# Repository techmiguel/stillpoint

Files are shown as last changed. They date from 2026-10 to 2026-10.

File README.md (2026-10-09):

<p align="center">
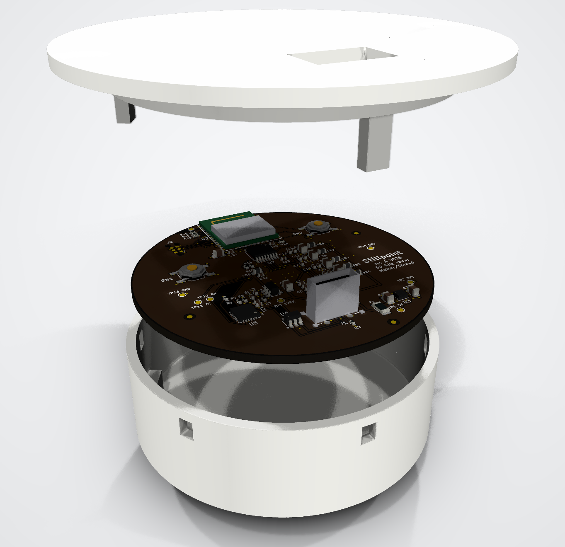
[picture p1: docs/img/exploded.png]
Stillpoint exploded view: lid, board and enclosure with its radome
  
</p>

<h1 align="center">Stillpoint</h1>

<p align="center">
  <b>A privacy-first ceiling sensor that counts people, knows their posture and reports falls,<br>
  using a 60 GHz radar instead of a camera.</b>
</p>

<p align="center">
  
  
  
</p>

<p align="center"><a href="https://techmiguel.github.io/stillpoint/"><b>Project page →</b></a></p>

- **Sees the room, never the person.** No camera, no microphone. A 60 GHz FMCW radar
  (Infineon BGT60TR13C) measures where people are and how they move.
- **Finds people who are perfectly still**, by the movement of their chest as they
  breathe, so someone sitting or lying quietly does not "disappear".
- **Counts people, tracks position and posture, and reports falls**, all from one stream:
  no modes to switch between.
- **Runs entirely on the device** (Silicon Labs MGM260P / EFR32MG26) and reports over
  **Matter on Thread** with standard clusters: no cloud, no account, works with Home
  Assistant.
- **Open hardware**: KiCad schematic and 4-layer Ø60 mm board, FreeCAD enclosure, C
  firmware and the Python reference it is tested against.

> **Not a medical device.** A fall alert is a notification, never the only safety measure
> for a person.

## The board

| Top (ceiling side) | Bottom (radar, faces the floor) |
|---|---|
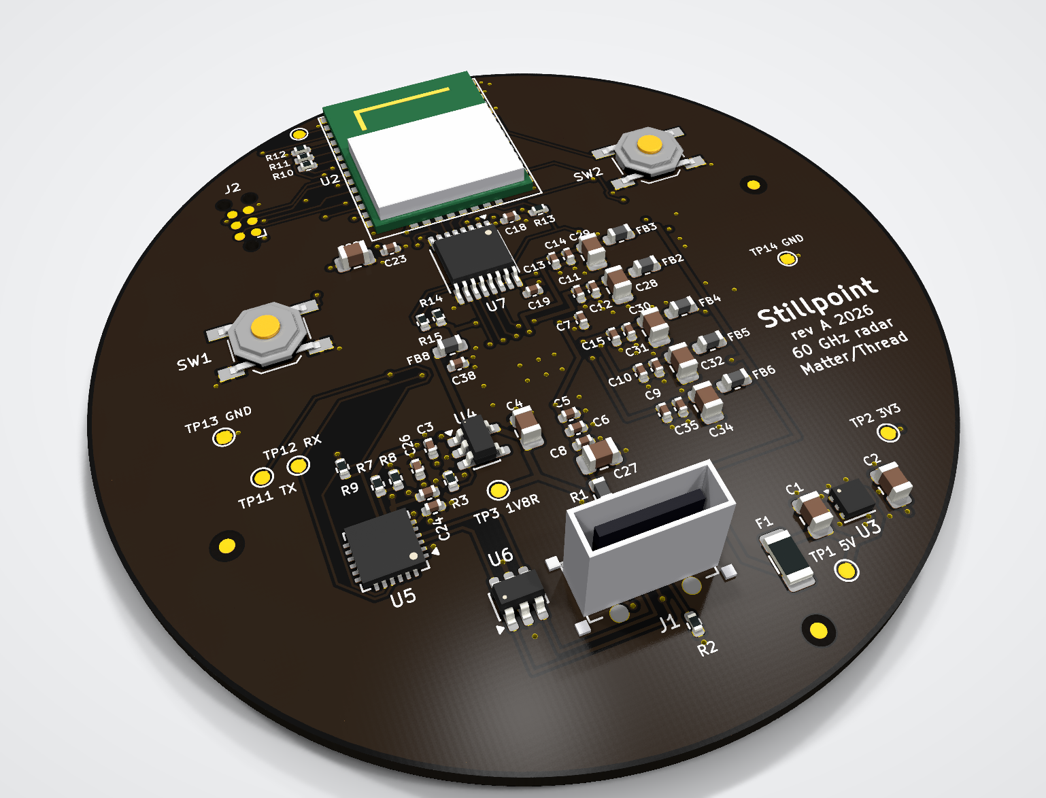
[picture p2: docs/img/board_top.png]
Stillpoint board, top
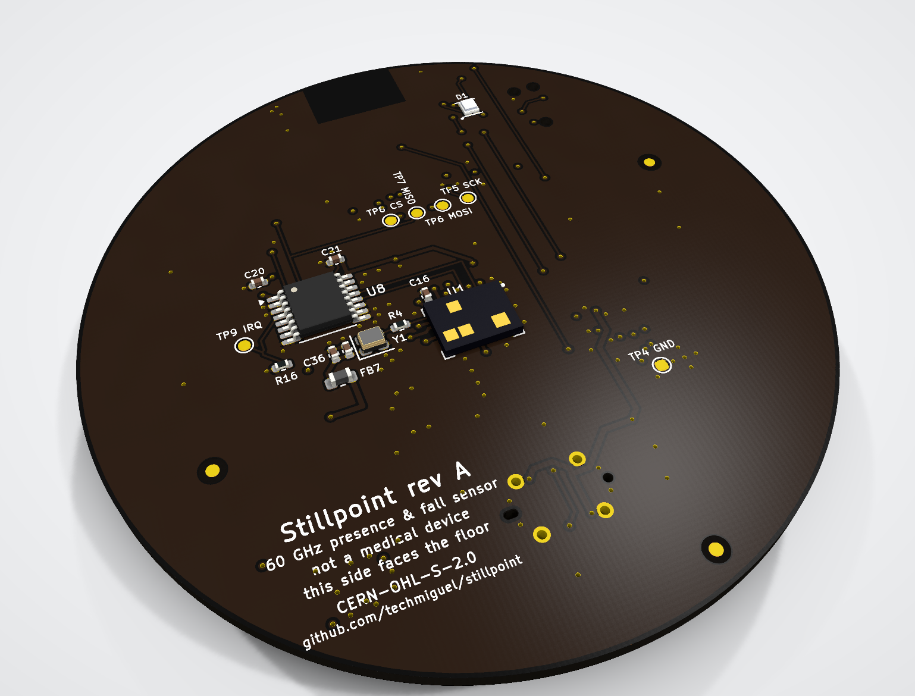
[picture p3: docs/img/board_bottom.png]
Stillpoint board, bottom
|  |  |

| | |
|---|---|
| Size | Ø60 mm round, 4 layers, 1.6 mm, ENIG, JLCPCB standard process |
| Radar | BGT60TR13C on the bottom face, 0.5 mm-pitch BGA, antennas in package |
| Radio + CPU | MGM260P module (Cortex-M33 + MVP accelerator, Matter/Thread/BLE) at the board edge with its antenna keep-out |
| Power | USB-C, 3.3 V LDO, 7 µVrms 1.8 V LDO for the radar, one π filter per radar supply domain |
| Extras | CP2102N USB console, RGB status LED, setup/reset buttons, Tag-Connect SWD, 14 test points |

Layout highlights:

- **Radar ground done by the book.** Solid ground on L2, a ground island on L3 right under
  the chip, nothing but ground vias inside the ball ring, and a custom DRC rule that keeps
  every other net off the inner layers under the radar.
- **Every radar supply is a straight lane** from its ball through 100 nF → 1 µF → 10 µF to
  its ferrite, with the smallest capacitor closest to the ball (Infineon's reference
  filter).
- **No crossing radar lines.** The radar signals leave the MCU from the pad row that faces
  the level translators, and the two translators are split over both faces to match the
  radar's ball order.

Fabrication files (Gerber, drill, BOM and CPL for JLCPCB, schematic PDF, STEP) are in
[`hardware/fabrication/`](hardware/fabrication) and attached to the
[rev A release](https://github.com/techmiguel/stillpoint/releases/tag/rev-a).
Full design notes: [docs/hardware.md](docs/hardware.md).

## The enclosure

A Ø65 mm, 24 mm tall ceiling puck on a Ø77 mm ceiling plate, 3D-printed in natural PETG.
The bottom of the shell is the radome: a flat slab exactly half a wavelength thick inside
the plastic (1.48 mm), so the 60 GHz signal passes through with about 0.15 dB of loss, and
the radar's antennas sit one wavelength (4.95 mm) above it. The board rests on three supports and the lid clamps it
with three posts at the same angles; the USB-C cable leaves through the lid, against the
ceiling.

The FreeCAD model ([`mechanical/enclosure.py`](mechanical/enclosure.py)) loads the real
board STEP and checks that nothing touches the shell, the lid or the radome, and that no
plastic sits in the antennas' ±60° field of view.

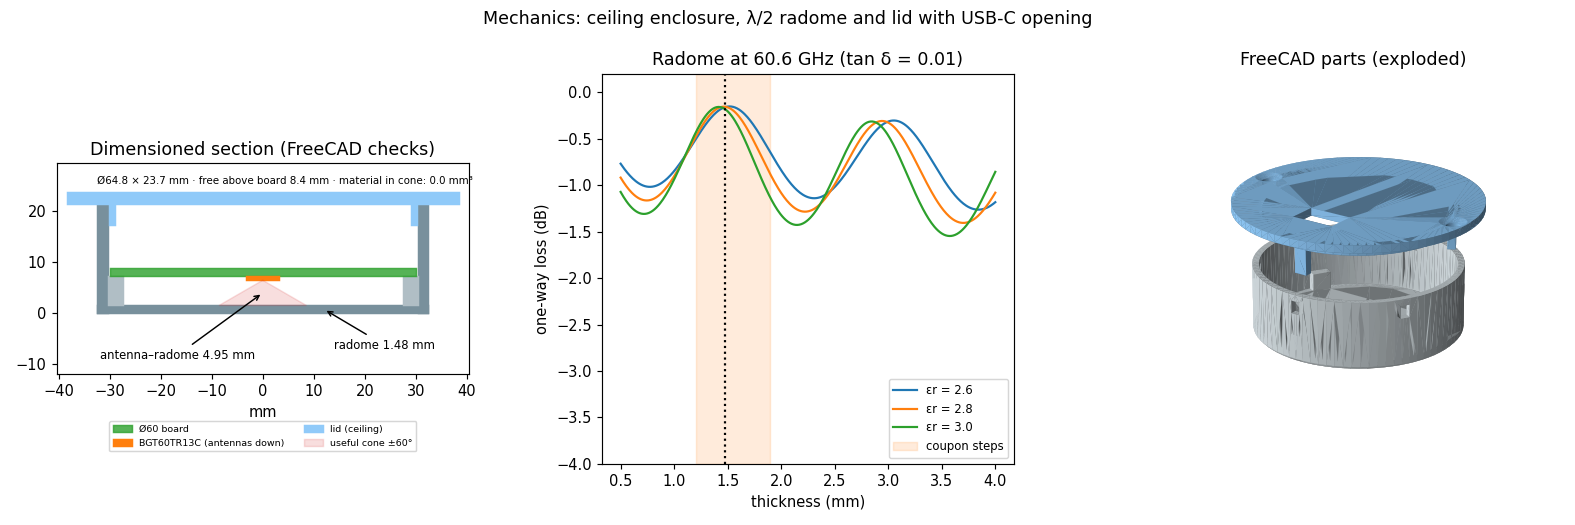
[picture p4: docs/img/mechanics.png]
Enclosure section, radome transmission and parts


## How it works

```
ADC (3 RX × 32 chirps × 128 samples, 10 Hz)
  → range FFT ─┬─ motion path: MTI + Doppler + CFAR + angle   (people who move)
               └─ micro-motion path: 10 s of phase, breathing  (people who are still)
  → 3D detections → tracks with room logic (doors, occlusion, ghosts)
  → 66-byte feature record per track (the contract)
  → int8 CNN (14.6 KB) every 0.5 s → fail-safe decision → Matter
```

The fixes for the classic failures of commercial radar sensors are regression tests:

| Scenario | What the sensor does |
|---|---|
| A person sits still and someone walks in front of them | the hidden person is kept as *occluded*, never dropped |
| An empty room with a fan running | the fan is learned as an interferer and not counted |
| Someone walks next to a mirror | the mirror ghost is recognised as multipath |
| A fall | suspected by the model or by a fast drop to the floor, confirmed after 4 s still on the floor; if it cannot be verified it is reported as *uncertain*, never silenced ([plot](docs/img/fall_events.png)) |

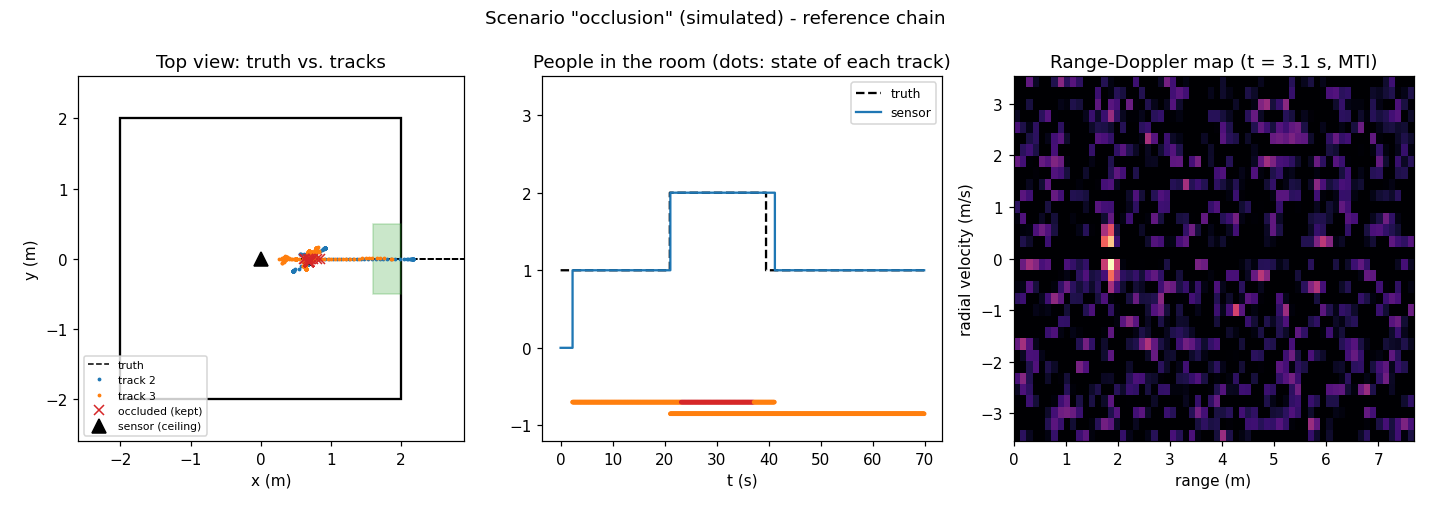
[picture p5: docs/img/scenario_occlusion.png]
occlusion scenario


The C firmware is checked frame by frame against the Python reference: same counts,
≥ 99.8 % identical quantized features, and identical postures, fall decisions and alarm
times ([plot](docs/img/app_c_vs_python.png)).

## License

[CERN-OHL-S-2.0](LICENSE) (CERN Open Hardware Licence v2, strongly reciprocal) for the
whole project: schematic, board, mechanics, firmware and documentation.

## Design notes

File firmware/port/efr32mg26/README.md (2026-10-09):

# EFR32MG26 port (Matter over Thread)

Everything that does not depend on the SDK lives in `firmware/src/` and is
tested on the PC against the Python reference
(`cd ml && python -m unittest discover -s tests`). This folder holds only the
layer that **does** depend on the Silicon Labs SDK. It has **not been built
against the real SDK yet**. `radar_port.c` and `diag_uart.c` pass
`gcc -fsyntax-only -Wall -Wextra` against stub headers that carry the SDK and
Infineon driver signatures. That rules out type and name errors, not mismatches
with the real signatures. Building and testing with the kit is phase F2.

| File | What it does | Status |
|---|---|---|
| `radar_port.c` | Infineon driver platform hooks (SPI, CS, RST, delay), FIFO interrupt, radar task | syntax-checked |
| `radar_settings_check.h` | refuses to build with a `radar_settings.h` that differs from config v1 | not built |
| `radar_pins.h` | rev A board pins (radar, LED, button, console) | matches `hardware/` and `verification/pcb/pins.yaml` |
| `matter_bridge.cpp` | `rf_outputs_t` → Matter attributes (EP1–6 plus the manufacturer cluster with `ContractVersion` and `ModelHash`), at most 2 reports/s except alarms | not built; ZAP generates the `StillpointPresence::…` accessors from the XML |
| `app_radar_init.cpp` | start-up from `AppTask::AppInit` | not built |
| `diag_uart.c` | contract records over UART with COBS (`tools/diag_reader.py`) and command input (room configuration from `tools/room_cfg.py`, acknowledged) | COBS tested on PC; syntax-checked |
| `cfg_store.c` | room configuration in NVM3 (v1 layout from `src/room_cfg.h`); factory default when none is valid | `room_cfg.c` tested on PC against the Python tool; syntax-checked |
| `stillpoint_cluster.xml` | manufacturer cluster for ZAP | not validated in ZAP |

## Steps (F2)

1. Simplicity Studio 5 + Simplicity SDK + Silicon Labs Matter extension.
2. New project from the **Matter – SoC Occupancy Sensor (Thread)** example for the
   EFR32MG26 board.
3. Components: `spidrv` (instance `radar`, EUSART1, 12 MHz to start with; on the
   rev A board SCLK PA07, MOSI PA08, MISO PC00 and CS as GPIO, see `radar_pins.h`),
   `gpiointerrupt`, `sleeptimer`, `iostream_eusart` or `iostream_usart` for
   diagnostics (3 Mbaud, non-blocking reads) and `nvm3_default`. Check that the
   NVM3 key in `cfg_store.c` (0x0F600) is outside the range Matter reserves.
   The board's module is the MGM260PB32VNA5 (+20 dBm, the same as the kit); the
   3.3 V regulator (TLV75733P, 1 A) is sized for its TX peaks (budget in
   [`docs/hardware.md`](../../../docs/hardware.md)).
4. Add `firmware/src/*.c` (except tests), this folder and Infineon's
   `sensor-xensiv-bgt60trxx` library (Apache-2.0) without its `*_mtb.c`.
5. Export `radar_settings.h` from **Infineon Radar Fusion GUI** with:

   | Parameter | Value |
   |---|---|
   | Start / stop frequency (sampled) | 60.0 / 61.25 GHz |
   | Samples per chirp | 128 at 2 MS/s |
   | Chirps per frame | 32, 350 µs repetition |
   | Frame | 100 ms (10 Hz) |
   | RX | 1, 2, 3 · TX 1 |

   `radar_settings_check.h` fails the build if anything differs.
6. ZAP: endpoints from [`docs/matter.md`](../../../docs/matter.md) (EP1 occupancy,
   EP2–4 zones, EP5 fall and EP6 uncertainty as Boolean State) and the
   `stillpoint_cluster.xml` cluster.
7. Call `RadarInit()` at the end of `AppTask::AppInit()`.
8. Measure on the kit: `rf_app_frame` cycles (TP10 GPIO + oscilloscope), free RAM,
   and compare the diagnostic stream with the reference on the same scenario
   (`tools/diag_reader.py` + `ml/compare_c.py`).

## Planned speed-ups

| Portable (tested) | Accelerated on the MCU | Acceptance |
|---|---|---|
| `rf_fft` | CMSIS-DSP `arm_cfft_f32` / MVP | contract records ≥ 99 % identical in `ml/compare_c.py` |
| `rf_dft_bin` (micro-motion) | zero-padded 128-point FFT or Goertzel | same |
| `nn.c` | TFLite Micro + MVP kernels | logits identical to `firmware/tests/nn_vectors.h` |

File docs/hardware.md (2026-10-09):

# Hardware (rev A)

A round Ø60 mm, 4-layer board that mounts on the ceiling. The 60 GHz radar sits on the
bottom face and looks at the floor through the radome; the Matter/Thread module sits at
the board edge with its built-in antenna. This page explains *why* the board is the way
it is. The sources are in [`hardware/`](../hardware) and the fabrication files in
[`hardware/fabrication/`](../hardware/fabrication).

| Top (ceiling side) | Bottom (faces the floor) |
|---|---|
| top | bottom |

The board was designed ahead of phases F1–F2 so it is ready when the kits have validated
the architecture. **It is not ordered before F2 closes**: any pin, clock or power change
the kits ask for lands here first.

## At a glance

| | |
|---|---|
| Size | Ø60 mm, 1.6 mm, 4 layers (JLCPCB JLC04161H-7628), ENIG, black mask |
| Parts | 74 placed (62 top, 12 bottom), 30 BOM lines, every one with MPN and LCSC number |
| Routing | 897 mm of track (635 mm top, 262 mm bottom), 164 vias, no tracks on the inner planes |
| Rules | 0.15/0.12 mm track/space by default (0.1 mm minimum), 0.3/0.55 mm vias; all inside JLCPCB's standard process |
| Checks | ERC 0 errors, DRC 0 (any severity), 0 unconnected, 0 schematic/PCB differences (any severity), `kicadverify verify` PASS |

## Block diagram

```
USB-C 5 V ─ F1 0.75 A ─ U3 TLV75733P (WSON, thermal pad) ─ +3V3 (L3 plane)
   │                                │
   └─ U6 USBLC6 ─ U5 CP2102N ─ UART ┤          └─ FB4 ─ VDDLF (3.3 V)
                                    │
                         U2 MGM260P (EFR32MG26, Matter/Thread, antenna at the edge)
                                    │  SPI + IRQ + RST + OE   (3.3 V)
                         U7 / U8 SN74AVC4T245 level translators
                                    │  (1.8 V)
+3V3 ─ U4 TPS7A2018 (7 µVrms, EN = PC03) ─ +1V8_RAD ─┬─ FB1 RF  ─┬─ FB5 PLL
                                                      ├─ FB2 A    ├─ FB6 VCO
                                                      ├─ FB3 D    ├─ FB7 OSC ─ Y1 80 MHz XO
                                                      └─ FB8 IO (VCCB of U7/U8)
                                                                 └─ U1 BGT60TR13C (bottom)
```

## Stackup

| Layer | Use |
|---|---|
| L1 (F.Cu) | MCU, translator U7, radar supply filters, USB, LDOs; signals; GND pour |
| L2 (In1) | **solid GND** over the whole board (except the module antenna keep-out) |
| L3 (In2) | **+3V3 plane**, with a **solid GND island under the radar** |
| L4 (B.Cu) | BGT60TR13C radar, 80 MHz oscillator, translator U8, RGB LED; GND pour |

Every GND or +3V3 pad has its own via to its plane (98 GND and 25 +3V3 vias). Return
currents never run along long tracks, and +3V3 reaches the radio module, which pulls
162 mA peaks when it transmits, with low impedance.

## Radar (U1, BGT60TR13C, PG-VF2BGA-40-1, bottom face)

- Centred under the radome window, 2.5 mm south of the board centre to make room for
  the translator and the module. The enclosure script uses the same position.
- 0.275 mm pads per Infineon UG091722 fig. 5c. The ball map is a perimeter ring with an
  empty centre: 6 GND vias go there, and the L3 GND island plus the L2 GND plane form the
  solid "no signals under the chip" ground Infineon asks for. A custom DRC rule
  (`radar_ground_only` in [`stillpoint.kicad_dru`](../hardware/stillpoint.kicad_dru)) keeps any
  other net off the inner layers under the radar.
- Fan-out in two staggered via rows north of row 1 (CLK, DI, DIO3, CS, VDDD, VDDA) and
  east of column M (LF, PLL, VCO); RF leaves north (M1) and south (F9+G9). VAREF has its
  470 nF capacitor on the same face, right at the ball.
- IRQ and DO run between the vias to translator U8 on the bottom face. Row 1 alternates
  inputs and outputs, so U7 (outputs to the radar) is on top and U8 (inputs from the
  radar) on the bottom: no radar line crosses another.
- Kyocera KC2016 80 MHz crystal oscillator with a 150 Ω series resistor 4 mm from ball
  M2, with its own filter (FB7, 1 µF, 10 nF).

## Radar power

Each radar supply domain is a **straight 0.3 mm lane** from its BGA via through
100 nF → 1 µF → 10 µF, ending at its ferrite; the ferrites hang off a 0.4 mm +1V8_RAD
bus. This is the π filter of UG091722 fig. 6, with the smallest capacitor as close to the
ball as it can be. The source is a 7 µVrms LDO, because the radar allows ≤ 20 µVpp of
supply noise from 20 to 700 kHz.

## MCU (U2, MGM260P) and pin map

The module sits at the north edge, centred, with the antenna keep-out of its datasheet
(fig. 8.2: 8.8 × 4.8 mm, all layers). The 60 mm ground plane is exactly the width
Silicon Labs recommends for the built-in antenna.

The radar signals leave from the module's **bottom pad row**, which faces translator U7
directly (EUSART can be routed to any port):

| Signal | Pin | Pad | Goes to |
|---|---|---|---|
| SPI SCLK | PA07 | 16 | U7 2A2 → CLK |
| SPI MOSI | PA08 | 17 | U7 2A1 → DI |
| RST (DIO3) | PD03 | 18 | U7 1A2 → DIO3 |
| CS | PD02 | 19 | U7 1A1 → CS_N |
| SPI MISO | PC00 | 22 | U8 1A2 ← DO |
| IRQ | PC01 | 24 | U8 1A1 ← IRQ |
| Translator OE_N | PC02 | 25 | U7/U8 1OE+2OE, 10 k pull-up |
| RADAR_PWR_EN | PC03 | 26 | U4 EN, 100 k pull-down |
| LED R/G/B | PB00/PB01/PB02 | 6/5/4 | D1 (common anode) |
| Button | PB03 | 3 | SW1 |
| Console | PA05 RX / PA06 TX | 12/13 | CP2102N |
| SWD | PA01/PA02/PA03 | 8/9/10 | J2 Tag-Connect |

PD00/PD01 stay free for an optional 32.768 kHz crystal. The same map is in
[`radar_pins.h`](../firmware/port/efr32mg26/radar_pins.h) and
[`verification/pcb/pins.yaml`](../verification/pcb/pins.yaml).

Safe start-up: R13 holds the translators' OE high (outputs high-Z) and R3 holds the radar
LDO off while the MCU is in reset. Firmware powers the radar, waits for the LDO and the
oscillator, drives CS_N and DIO3 high and only then enables the translators
([`radar_port.c`](../firmware/port/efr32mg26/radar_port.c)).

## USB-C

J1 is a vertical USB-C receptacle (7.5 mm tall), so the cable leaves through the lid
against the ceiling. The two VBUS pairs join through the gap between the pin rows; D- is
joined A7–B7 through the gap and D+ A6/B6 on the bottom layer. The ESD part (USBLC6) is
flow-through: J1 goes to its south pins and its north pins go on to the CP2102N, which is
rotated 180° so the pair runs straight.

## Bill of materials

Full BOM with MPN and LCSC numbers: [`BOM_JLCPCB.csv`](../hardware/fabrication/BOM_JLCPCB.csv).

| Ref | Part | Function | Notes |
|---|---|---|---|
| U1 | Infineon BGT60TR13C (C3606641) | 60 GHz radar, 1 TX / 3 RX, antennas in package | bottom face; stocked at JLC |
| U2 | Silicon Labs MGM260PB32VNA5 | EFR32MG26: MCU + Thread/Matter + MVP, built-in antenna | certified module at the edge; not at JLC (consigned) |
| Y1 | Kyocera KC2016K80.0000C1GE00 | 80 MHz 1.8 V clock, jitter ≤ 1 ps | the one on Infineon's shield board; R4 150 Ω in series |
| U4 | TI TPS7A2018 | 1.8 V 7 µVrms LDO for the radar | EN from the MCU, pull-down |
| U3 | TI TLV75733P (WSON-6) | 3.3 V 1 A LDO | thermal pad with vias to GND |
| FB1–FB8 | Murata BLM18KG601SN1D | π filter per radar domain | 0.15 Ω, 1.3 A |
| U7, U8 | TI SN74AVC4T245 | 3.3 V ⇄ 1.8 V translators | OE active low with pull-up |
| U5 | Silicon Labs CP2102N | USB ⇄ UART | 3 Mbaud records |
| U6 | ST USBLC6-2SC6 | ESD on D+/D- and VBUS | |
| J1 | G-Switch GT-USB-7051A | vertical 16-pin USB-C | cable leaves through the lid |
| F1 | PTTC SMD1206P075TFT | 0.75 A resettable fuse | |
| J2 | Tag-Connect TC2030-NL | SWD + reset + SWO | footprint only |
| D1 | Yongyu SZYY1615RGB-B | common-anode RGB status LED | bottom face, seen through the radome; ~2 mA per colour |
| SW1, SW2 | E-Switch TL3342 | setup / reset | |

## Checked against the datasheets

| Part | What was checked | Result |
|---|---|---|
| BGT60TR13C (table 1) | 40 balls and their functions | matches the schematic and `verification/pcb/pins.yaml` |
| BGT60TR13C | 1.8 V I/O (2 V absolute max) | level translators on CLK, DI, CS_N, DIO3, DO and IRQ |
| BGT60TR13C (§8.1) | VAREF | low-ESR **470 nF** (C16) next to ball L1 |
| BGT60TR13C (table 5) | supply noise ≤ 20 µVpp at 20–700 kHz | TPS7A2018 (7 µVrms) and a π filter per domain, 100 nF + 1 µF + 10 µF |
| BGT60TR13C (table 5) | clock 75–85 MHz, CMOS 1.8 V, jitter ≤ 1 ps | Kyocera KC2016 crystal XO; a MEMS SiT8008 (1.3–2 ps) does not qualify |
| BGT60TR13C | max TX power +5 dBm, antenna gain 3.5 dBi typ. | **≈ 10 dBm EIRP max**, below the EU 20 dBm |
| Shield board UG091722 (fig. 5c, §3.3, §3.4) | land pattern, filters, clock series resistor | 0.275 mm pads; filter per domain; R4 150 Ω, tuned on the bench |
| MGM260P (table 2.1, 6.1, fig. 8.1, 8.2) | ordering code, pinout, land pattern, height, antenna keep-out | MGM260PB32VNA5 (+20 dBm); 11.30 mm columns, 2.4 × 0.6 pads, 8.8 × 4.8 mm keep-out; 2.35 mm max height fits under 8.4 mm of free space |
| GT-USB-7051A (drawing) | land pattern and height | holes ±2.4/±2.15, slots ±3.75, 7.5 mm tall; the centre pegs are plastic, no holes |
| SN74AVC4T245 | DIR/OE, unused inputs | DIR high A→B, OE active low with pull-up; U8 2B1/2B2 tied to GND as TI requires |
| CP2102N (fig. 2.3) | self-powered without the regulator, RSTb, VBUS sense | VREGIN = VDD = 3.3 V, 1 kΩ on RSTb, 22.1/47.5 kΩ divider; **4.7 µF + 0.1 µF** decoupling |
| USBLC6-2 | pinout | correct; D+/D- flow through the part |
| SZYY1615RGB-B | pinout | 1 R, 2 G, 3 B, 4 common anode (LCSC pattern of C3029071), same as the symbol |

Datasheet links: [references.md](references.md).

## Design review history

The first schematic passed its pin checks but failed review on three component choices
that would have hurt the radar or the 2.4 GHz radio. They were fixed before layout:

| Before | After | Why |
|---|---|---|
| AP2112K-1.8 radar LDO (50 µVrms) | TPS7A2018 (7 µVrms), same SOT-23-5 pinout | the radar allows < 20 µVpp from 20 to 700 kHz |
| SiT8008 MEMS oscillator (1.3–2 ps) | KC2016 crystal XO (≤ 1 ps) with its own ferrite and a tunable series resistor | radar clock jitter limit; matches Infineon's shield board |
| One shared 1.8 V rail | separate π filter for RF, A, D, PLL, VCO, OSC and LF; translator VCCB on its own branch | UG091722 §3.3, fig. 6; keeps SPI noise out of the radar's digital supply |
| 3.3 V LDO in SOT-23-5 | TLV75733P in WSON-6 with thermal pad | 0.7 W peak would heat a SOT-23-5 by ~128 °C |
| Translators always enabled | OE_N with pull-up, CS_N/DIO3 pull-ups, IRQ pull-down | defined levels while the MCU is in reset |

## Power budget

Estimated; measured in F2. U3 brings everything from 5 V to 3.3 V, including the radar
through U4. Frame cycle: 32 chirps of 350 µs every 100 ms plus ~2 ms of start-up and FIFO
read (13 % of the time).

| | 3V3 | Dissipation in U3 |
|---|---|---|
| Peak (radar active and TX at +20 dBm together) | ≈ 410 mA | ≈ 0.70 W, only during the overlap |
| Average | ≈ 60 mA | ≈ 0.10 W |

U4 dissipates (3.3 − 1.8) V × 230 mA ≈ 0.34 W during each burst and about 50 mW on
average. Assumptions (datasheets): radar 230 mA active (max) and 2.8 mA idle; MGM260P
162 mA transmitting at +20 dBm (1 % of the time), 6 mA receiving and about 4 mA of CPU;
CP2102N 10 mA; LED about 2 mA per colour. The 5 V peak stays below 0.45 A, well under the
0.75 A hold current of F1. If less power were needed, the MGM260PB22VNA5 (+10 dBm) has the
same package and pinout.

## Test points

| TP | Signal | Use |
|---|---|---|
| TP1–TP3 | 5 V, 3.3 V, 1.8 V radar | bring-up and current measurement |
| TP4, TP13, TP14 | GND (×3, spread out) | probes |
| TP5–TP8 | radar SPI SCLK, MOSI, MISO, CS | logic analyser |
| TP9 | radar IRQ | latency and frame timing |
| TP10 | "frame processed" GPIO | DSP cycle time on a scope |
| TP11–TP12 | UART TX/RX | console without USB |

## Mechanics

- The board rests on three enclosure supports at 30°, 150° and 270° and the lid clamps it
  with three posts at the same angles: both faces are kept free of parts there
  (`SUPPORT_*` zones on the board).
- The λ/2 radome (1.48 mm for εr = 2.8) sits exactly 4.95 mm (λ0) from the antennas.
- [`mechanical/enclosure.py`](../mechanical/enclosure.py) loads the real board STEP (every
  part with a 3D model) and asserts that nothing touches the enclosure, the lid or the
  radome and that there is no material in the ±60° antenna cone. Results in
  [`checks.json`](../mechanical/cad/checks.json): 0 mm³ of interference, tallest part
  7.5 mm (USB-C) against 8.4 mm of free height.

mechanics

## Verification

- ERC: 0 errors. The 2 warnings are intended: U8's unused B-side inputs are tied to GND,
  as TI requires.
- DRC: **0 violations of any severity**, 0 unconnected, 0 schematic/PCB parity issues of
  any severity, with the rules in `stillpoint.kicad_pro` and `stillpoint.kicad_dru`.
- The schematic is laid out by function, with block headings; [`tools/sch_tidy.py`](../tools/sch_tidy.py)
  keeps every pin label pointing away from its symbol and every reference and value clear
  of the labels.
- [`kicadverify verify`](https://github.com/techmiguel/kicad-verify): ERC, DRC, parity, pin
  maps against the datasheets ([`pins.yaml`](../verification/pcb/pins.yaml)), circuit
  checks, Gerber/drill/BOM/CPL against the board: **PASS**. Each exception is in
  [`waivers.yaml`](../verification/pcb/waivers.yaml) with its reason.
- Still open, needing the board in hand (HUM-* sign-offs): 1:1 print, polarities, CPL
  rotations in the JLCPCB viewer, prototype bring-up.

## Fabrication (JLCPCB)

```bash
python tools/export_fab.py
```

writes Gerber (X2), Excellon drills, JLCPCB BOM and CPL, the schematic PDF and the board
STEP to `hardware/fabrication/`, always from the current board.

- Double-sided assembly. The BGT60TR13C is stocked at JLC (C3606641). The MGM260P and the
  KC2016 are not: Global Sourcing or consigned parts. Check the CPL rotations in the
  fabricator's viewer before ordering.
- J2 is only the footprint for the Tag-Connect TC2030-NL cable: not fitted, not in the BOM.
- Rev A batch: 5 boards; 2 kept for destructive and thermal tests.

## Bring-up checklist

1. Before the radar: rails, idle current, USB enumerates.
2. SWD: flash the diagnostic firmware; the UART answers.
3. Measure +3V3 and +1V8_RAD on TP2 and TP3 with RADAR_PWR_EN high; check the 80 MHz
   clock at R4.
4. Read the radar ID over SPI (TP5–TP8); take a test frame; with the room empty the
   spectrum shows no fixed spurs. Tune R4 on the range-Doppler map (UG091722 §3.4).
5. Same scenario as on the kit: the contract records must match the kit's in
   distribution (presence, count, height).

## How the layout was made

Placement and every critical route (BGA escape, radar supply lanes, USB-C breakout and
pair) are written as scripts in [`tools/pcb_build/`](../tools/pcb_build); Freerouting
routes the rest without touching the locked items. Every decision can be read in code and
the board can be rebuilt from the schematic with `sh tools/pcb_build/pipeline.sh`.

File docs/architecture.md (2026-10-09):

# Architecture

## Blocks

```
 USB-C 5V ─► LDO 3V3 (MCU) ─┬─► low-noise LDO 1V8 (radar)
          └─► CP2102N (USB data ⇄ UART)
                             │
 ┌──────────────┐  SPI 50 MHz + IRQ + RST  ┌──────────────────────────────────────┐
 │ BGT60TR13C   │ ───────────────────────► │ EFR32MG26 (Cortex-M33 + MVP)         │
 │ 1 TX / 3 RX  │  FIFO → DMA              │  DSP: range FFT, MTI+Doppler, CFAR,  │
 │ AiP antennas │                          │       angle, micro-motion            │
 └──────────────┘                          │  Tracking + room logic               │
      PETG radome ~1.5 mm (λ/2)            │  Features (contract v1)              │
                                           │  int8 classifier (MVP) + decision    │
                                           │  Matter / Thread (FTD router) / BLE  │
                                           └──────────────────────────────────────┘
                                             SWD · UART · test points
```

Per frame (10 Hz): ADC samples → range FFT → two paths (motion and micro-motion) → 3D
detections → tracks → one 66-byte record per track. At 2 Hz every track with 2 s of
history goes through the classifier and the decision state machine; changes are
published over Matter.

The reference implementation is [ml/radarref](../ml/radarref). The firmware ports it
block by block and is compared against it **on the contract** (the feature records),
not on the intermediate steps.

## Key decisions

1. **Two detection paths.** Classic MTI erases whoever does not move; the breathing path
   brings them back. That is the root cause of "a still person disappears".
2. **Room logic.** People enter and leave through doors. A confirmed track is only dropped
   quickly next to an exit zone; in the middle of the room it is kept (60 s when occluded,
   120 s if it has shown breathing).
3. **No modes.** Zones, posture and falls all come from the same track stream.
4. **The model never sees absolute position.** x, y, range and track state are excluded
   from its input so it cannot learn the geometry of the training rooms.
5. **Physics rule + model for falls.** A suspicion opens on the model *or* on a fast
   descent to the floor; confirmation needs the person to stay on the floor and still for
   4 s. No single component can trigger or silence an alarm.

## Component choice

| Option | Pros | Cons | Decision |
|---|---|---|---|
| **A. EFR32MG26** (single chip) | Matter + Thread + BLE in one chip with a mature SDK; MVP accelerator; up to 3.2 MB flash / 512 kB RAM | MVP is a matrix accelerator, not a full NPU; 78 MHz | **v1** |
| B. PSoC Edge E84 + EFR32MG24 | Ethos-U55 NPU, more CPU; Infineon sells a kit with the same radar | two chips, Thread through an RCP, more BOM and firmware | plan B if F2 runs out of CPU |
| C. nRF54L15 | good Matter support in Zephyr | no AI accelerator | rejected |

The current model is 14.6 KB and needs ~0.1 M MAC per inference: the AI load is small.
The expected bottleneck is the DSP, not inference.

## Radar parameters (v1)

| Parameter | Value | Consequence |
|---|---|---|
| Sweep | 60.0–61.25 GHz (1.25 GHz) | 12 cm range resolution |
| Samples/chirp | 128 real at 2 MS/s | 64 bins → 7.7 m |
| Chirps/frame | 32 every 350 µs | v max ±3.5 m/s, 0.22 m/s resolution |
| Frames | 10 Hz, 11 % duty cycle | |
| RX antennas | L-shaped, λ/2 | azimuth and elevation → 3D position and height |

## Compute and memory budget

Estimated; measured in F2.

| Block | Cycles/frame (est.) | RAM (est.) |
|---|---|---|
| Range FFT 96 × 128 real (q15) | ~0.5 M | 24 KB in + 24 KB out |
| MTI + Doppler 3 × 40 × 32 complex | ~0.3 M | 15 KB |
| CFAR + angle + clustering | ~0.2 M | 4 KB |
| Micro-motion (every 5 frames, 100 × 3 × 40) | ~0.4 M amortized | 48 KB |
| Tracking + features | < 0.1 M | 4 KB |
| Classifier (2 Hz × 3 tracks) | < 0.1 M amortized | 16 KB arena |
| **Total** | **~1.5 M of 7.8 M available (≈ 20 %)** | **~140 KB** + Matter stack |

If F2 measures more than 50 % CPU or less than 64 KB free RAM, plan B starts.

## Firmware tasks

| Task | Priority | Period | Input → output |
|---|---|---|---|
| `radar_isr` / DMA | ISR | FIFO | SPI → frame buffer |
| `dsp` | high | 100 ms | frame → detections |
| `track` | high | 100 ms | detections → tracks + records |
| `infer` | medium | 500 ms | windows → posture/fall |
| `matter` | medium | on events | state → attributes/events |
| `diag` | low | on demand | records over UART/USB (data capture) |

All of `firmware/src/` is portable C, tested on the PC against the Python reference.
The SDK-dependent layer is in [firmware/port/efr32mg26](../firmware/port/efr32mg26).

## Interfaces

Each block has one owner. An interface change is proposed by whoever produces the data
and approved by whoever consumes it. In a one-person team the roles still apply: every
deliverable is reviewed wearing the consumer's hat before it is accepted.

| ID | From → to | Format | Source of truth | Test that guards it |
|---|---|---|---|---|
| I1 | Radar → DSP | int16 ADC frame (3 × 32 × 128) | `RadarConfig` / `radar_limits.h` | `RadioLimitsTest`, `test_limits` (C) |
| **I2** | **DSP → ML** | **feature record v1, 66 bytes** | **[contracts/features_v1.yaml](../contracts/features_v1.yaml)** | `ContractTest`, `golden_v1.h` (C) |
| I3 | ML → firmware | `model_int8.tflite` + `model_meta.json` + `model_data.h` | `ml/train.py` | `model_guard.h` (does not compile on a hash mismatch) |
| I4 | Firmware → home automation | Matter (endpoints and clusters) | [matter.md](matter.md) | bench M1–M3 |
| I5 | Hardware ⇄ mechanics | board outline, antenna–radome distance, supports | `mechanical/enclosure.py` | interference check against the board STEP; radome coupon |
| I6 | Everyone → bench | event CSVs with an NTP clock | [test-bench.md](test-bench.md) | `ml/tests/test_bench.py` |

### I2 in detail: the feature contract

This is the interface that does the most damage if it breaks silently: a model trained
on a different scale keeps "working" and returns garbage.

- 24 `int16` fields in scaled physical units (mm, mm/s, cdB, mHz…). List and scales in the YAML.
- A CRC-32 hash of the canonical form (name | unit | scale + window parameters). It
  travels in every record (16 bits) and in the model (32 bits).
- The firmware **does not compile** with a model from another contract
  (`_Static_assert` in `model_guard.h`) and the Python reference **refuses to load** it
  (`ModelMismatch`).
- Training uses the values *after* quantize/dequantize: the model sees exactly what it
  will see on the board.
- Golden vectors: `tools/gen_contract.py` writes the expected bytes from Python;
  `firmware/tests/test_host.c` requires C to produce the same ones.
- Normalization (mean/std) and the out-of-distribution limits live in
  `model_meta.json`, not in the contract.
- Changing order, unit, scale or meaning ⇒ `features_v2.yaml`. Published versions are
  never edited.

After changing the contract:

```bash
python tools/gen_contract.py
```

```bash
make -C firmware test
```

```bash
cd ml && python -m unittest discover -s tests
```

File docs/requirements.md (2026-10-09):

# Requirements

## What it is

A USB-C powered ceiling sensor. A 60 GHz FMCW radar tells how many people are in
**one** room, where they are, their posture (standing, sitting, lying) and whether
someone fell. There is no camera and no microphone. All processing runs on the device
and the result is published over Matter on Thread: no cloud, no account.

## What it is not

- **Not a medical device.** A fall is a *notification*, never the only safety measure
  for a person. This sentence goes in the README, on the box and in the Matter device
  description.
- It does not measure vital signs with clinical value. Breathing is only used as
  evidence that someone is there.

## v1 scope (frozen)

| Topic | v1 | Out of v1 |
|---|---|---|
| Rooms | 1, up to 4 × 4 m | several rooms, corridors |
| Mounting | ceiling, 2.4–2.9 m, antennas facing the floor | wall, corner |
| People | up to 3 (criteria measured with 1–2) | more than 3, pets |
| Radar | BGT60TR13C with antennas in package | custom antennas |
| Power | USB-C 5 V | battery |
| Output | Matter 1.3+ over Thread | Wi-Fi, Zigbee, cloud |

## Known failures of commercial sensors, and the design answer

| Reported problem | Design answer | Where it is checked |
|---|---|---|
| Ghost detections (fan, mirror) | room limits, excluded zones, multipath filter, fixed sources with micro-Doppler but no breathing are learned as interferers | `test_fan_becomes_interferer`, `test_mirror_ghost_not_counted`, bench G1–G3 |
| A still person vanishes when someone walks in front | a breathing (micro-motion) path independent of MTI; an OCCLUDED track state; tracks are only dropped quickly next to a door | `test_still_person_survives_occlusion`, bench O1–O2 |
| Mutually exclusive modes (sleep / zones / fall) | one track stream; zones, posture and falls are always computed together; the compute budget is sized for the worst case | [architecture](architecture.md#compute-and-memory-budget) |
| Battery trade-offs | out of v1 scope: mains powered | — |
| Ecosystem lock-in | standard Matter; local configuration; no account | [matter](matter.md), bench M1 |
| No independent metrics | criteria fixed before starting, published bench, comparison with a commercial sensor, confidence intervals | below, [test bench](test-bench.md) |

## Technical guardrails

- Every number below was fixed before any design work.
- The whole chain is validated on evaluation kits before a board is ordered ([plan](plan.md)).
- Fail safe: without confidence the output is "uncertain"; a possible fall that cannot be
  verified is published as "uncertain fall", never silenced
  ([decision.py](../ml/radarref/decision.py)).
- Emission stays inside 57–64 GHz and ≤ 20 dBm EIRP, enforced in firmware
  ([regulatory](regulatory.md), [radar_limits.h](../firmware/src/radar_limits.h)).
- The board has SWD, UART, USB data and test points on every rail ([hardware](hardware.md)).

## Data guardrails

- Written consent from everyone recorded ([data protocol](data-protocol.md)).
- Training and test are split by person **and** by room; the code enforces it
  ([split.py](../ml/radarref/split.py)).
- Falls are simulated by healthy adults on a crash mat; every published fall metric says so.
- Public datasets and the simulator are for prototyping only: no final model is trained
  only on them and no published metric comes from them.

## Acceptance criteria (v1)

Fixed on 2026-10-05, **before** any hardware. Changing one requires logging the date,
the reason and the old value at the end of this document; they are never tuned to make
a result pass.

Every metric is measured on the [test bench](test-bench.md), on people and rooms that
were not used for training, and is published with its n and its 95 % confidence interval.

### Presence

| ID | Metric | Threshold | How |
|---|---|---|---|
| P1 | Occupied minutes detected as occupied (including still people sitting or lying) | ≥ 99 % | per minute, ≥ 20 occupied hours |
| P2 | Still person who vanishes when another walks in front | 0 cases in ≥ 50 passes (95 % upper bound ≤ 6 %) | scenarios O1–O2 |
| P3 | False occupancy in an empty room with fan, curtain and mirror | ≤ 1 per day | ≥ 7 empty days; exact Poisson |
| P4 | Latency entry → occupied | p95 ≤ 1.0 s | ≥ 50 entries |
| P5 | Latency exit through the door → empty | p95 ≤ 5 s | ≥ 50 exits |
| P6 | Exact count (0–3 people) | ≥ 90 % of the time | per second |
| P7 | Horizontal position error | median ≤ 0.30 m; p90 ≤ 0.50 m | against floor marks |

### Posture

| ID | Metric | Threshold |
|---|---|---|
| A1 | Macro F1 over standing, sitting, lying (non-abstained windows) | ≥ 0.85 |
| A2 | "Uncertain" rate in normal conditions | ≤ 5 % of the time |

### Falls

| ID | Metric | Threshold | Minimum n and why |
|---|---|---|---|
| F1 | Simulated falls notified (confirmed or uncertain) | ≥ 90 %, CI95 lower bound ≥ 80 % | ≥ 100 falls: at 90/100 the Wilson lower bound is 0.83 |
| F2 | False fall alarms in daily life | ≤ 0.1 per day | ≥ 30 sensor-days without an alarm (rule of three: 3/30 = 0.1) |
| F3 | Latency fall → Matter notification | p95 ≤ 10 s | ≥ 100 falls |
| F4 | Lying down in bed, sitting down hard, crouching | 0 alarms in ≥ 50 of each | scenarios A3–A5 |

### System

| ID | Metric | Threshold |
|---|---|---|
| S1 | Matter commissioning with Home Assistant | 10/10 without manual retries |
| S2 | Recovery after a Thread border router reboot | ≤ 60 s |
| S3 | Power | ≤ 1.0 W average at 5 V |
| S4 | Emission | 57–64 GHz and ≤ 20 dBm EIRP, by configuration and a rough measurement |
| S5 | Enclosure temperature | ≤ 15 °C above ambient |

### Kill criterion

At the end of phase F2 (the chain running on the kits, see [plan](plan.md)) the prototype
is compared with the commercial reference (Aqara FP2) on the same bench over the same
period. **If the prototype does not match the reference on P1, P2 and P3, the project
stops**, or is re-planned in writing, before a board is ordered.

### Criteria change log

| Date | Criterion | Before | After | Reason |
|---|---|---|---|---|
| — | — | — | — | — |

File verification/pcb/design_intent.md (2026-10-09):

# Design intent

Read by the independent reviewer. Facts the schematic cannot show; keep it short.

- Purpose of the board: ceiling-mounted 60 GHz FMCW presence/fall sensor (Infineon
  BGT60TR13C) with on-device DSP and Matter-over-Thread (MGM260P module). Not a
  medical device. Round Ø 60 mm, 4 layers, JLCPCB fab + assembly.
- Supply input: USB-C 5 V (default USB power, Rd = 5.1 k on CC1/CC2, no PD). USB 2.0
  data through CP2102N for logs at 3 Mbaud.
- Loads: radar 1.8 V 201 mA typ / 230 mA max active (duty-cycled frames);
  MGM260P up to 162 mA during +20 dBm TX bursts; CP2102N ~10 mA; RGB LED ~2 mA/colour.
  Worst-case simultaneous 3.3 V load ≈ 0.41 A.
- External connectors: J1 USB-C (power + data), J2 Tag-Connect TC2030-NL (SWD,
  reset, SWO) reachable with the enclosure open. SW1 commissioning, SW2 reset.
- Environment: indoor ceiling, closed plastic enclosure with a radome window,
  0–40 °C ambient. Radar on the BOTTOM side (B.Cu) facing the floor; nothing
  metallic in the ±60° cone in front of the antennas.
- Target fab/assembly: JLCPCB 4-layer 1.6 mm FR4 (JLC04161H-7628), ENIG, standard process
  (0.1 mm min track/space, 0.3/0.55 mm vias); BGT60TR13C is stocked at JLC (C3606641);
  MGM260P and the KC2016 XO are not, so they go through Global Sourcing or consignment.
- Stack-up: L1 parts + signals + GND pour; L2 solid GND; L3 +3V3 plane with a solid GND island
  under the radar; L4 radar (BGT60TR13C, oscillator, U8 translator, LED) + GND pour.
  Every GND / +3V3 pad has its own via to its plane.
- Radar supply filters: one 0.3 mm lane per domain from its BGA via on L1, through
  100 nF -> 1 uF -> 10 uF -> ferrite; a 0.4 mm +1V8_RAD bus feeds the ferrites.
- MCU pin map (rev A): radar SPI/control on the module's bottom pad row so the translators
  sit right below it: SCLK PA07 (16), MOSI PA08 (17), RST PD03 (18), CS PD02 (19),
  MISO PC00 (22), IRQ PC01 (24), OE_N PC02 (25), RADAR_PWR_EN PC03 (26). EUSART pins are
  routable to any port on MGM260P. PD00/PD01 left free for an optional 32 kHz crystal.
- Enclosure: board rests on three supports at 30/150/270 deg (bottom) and is clamped by
  three lid posts at the same angles (top); both faces are kept clear there (rule areas
  SUPPORT_*). USB-C J1 is vertical; the lid opening is centred over it.
- Decisions that look wrong but are intentional:
  - U7 (outputs to the radar) is on the top and U8 (IRQ/DO from the radar) on the bottom:
    the radar's row-1 balls interleave inputs and outputs, so splitting the translators
    over both faces is what lets every line route without crossings.
  - J2 (Tag-Connect TC2030-NL) is a pad pattern for the programming cable: nothing is
    mounted, so it is excluded from BOM and CPL and has no 3D model.
  - D1 is on the bottom (room-facing) side so it is visible through the radome.
  - Radar supply domains are split with ferrite pi filters per Infineon UG091722
    fig. 6; the radar 1.8 V LDO is fed from +3V3 (not 5 V) to keep its dissipation low.
  - Oscillator series resistor (R4, 150 Ω) is a tuning value per UG091722 §3.4.
  - SN74AVC4T245 translators run VCCA = 3.3 V (MCU side), VCCB = 1.8 V (radar side);
    unused B-side inputs of U8 are tied to GND on purpose.
  - MGM260P uses its built-in antenna (RFOUT pin 33 unconnected); it sits at the board
    edge opposite the radar with a copper keep-out per the module datasheet fig. 8.2.
  - BGT60TR13C DIV_TEST (M5) left unconnected (test output only).

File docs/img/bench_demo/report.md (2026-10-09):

# Bench report (DEMO DATA)

> Synthetic data from bench/demo_data.py, used to test the tool. It describes no product.

Duration: 24.0 h. Falls, when present, are simulated by healthy adults on a crash mat (docs/data-protocol.md).

| Criterion | Threshold | prototype | reference |
|---|---|---|---|
| P1 Occupied minutes detected | >= 0.99 | ✅ 99.7 % (609/611; CI95 98.8–99.9 %) | ❌ 98.4 % (601/611; CI95 97.0–99.1 %) |
| P3 False occupancies per day (empty room) | <= 1 | ❌ 1.79 (1 in 13.4 h; CI95 upper 9.95) | ❌ 0.00 (0 in 13.4 h; CI95 upper 6.59) |
| P4 Latency entry → occupied p95 (s) | <= 1 | ✅ 0.8 s (n=17) | ❌ 1.2 s (n=17) |
| P5 Latency exit → empty p95 (s) | <= 5 | ✅ 4.0 s (n=17) | ❌ 6.3 s (n=17) |
| F1 Falls notified | >= 0.9 | ❌ 100.0 % (11/11; CI95 74.1–100.0 %) | ❌ 0.0 % (0/11; CI95 0.0–25.9 %) |
| F2 False fall alarms per day | <= 0.1 | ❌ 0.00 (0 in 24.0 h; CI95 upper 3.69) | ❌ 0.00 (0 in 24.0 h; CI95 upper 3.69) |
| F3 Latency fall → notification p95 (s) | <= 10 | ✅ 8.3 s (n=11) | ❌ nan s (n=1), 1 missed |

Kill criterion (docs/requirements.md): prototype must match reference on P1, P2 and P3. P2 is measured separately with scenarios O1–O2.
- P1: prototype matches or beats reference.
- P3: prototype does NOT match reference.

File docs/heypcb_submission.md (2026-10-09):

# Circuit World submission (heypcb Hardware Challenge)

Text ready to paste when publishing the board from heypcb's Share menu.

## Title

Stillpoint — privacy-first 60 GHz presence & fall sensor (Matter over Thread)

## Summary (card)

A Ø60 mm ceiling sensor with no camera and no microphone. A 60 GHz FMCW radar counts
people, tracks where they are and their posture, flags falls, and still sees someone lying
completely still by the movement of their chest. Everything runs on the device and reports
over Matter/Thread: no cloud, no account.

## Description

**What it does**
- Infineon BGT60TR13C 60 GHz radar (1 TX / 3 RX, antennas in package) looking down from the
  ceiling through a λ/2 radome.
- On-device processing on the Silicon Labs MGM260P (EFR32MG26): range-Doppler + angle DSP,
  tracking, breathing micro-motion and an int8 neural network for posture and falls.
- Matter over Thread endpoints: occupancy, per-zone presence, fall and uncertainty.
- RGB status LED, commissioning button, USB-C power + 3 Mbaud log console (CP2102N).
- Not a medical device: a fall is a notification, never the only safety measure.

**How the board is made**
- 4 layers, Ø60 mm round, JLCPCB standard process (JLC04161H-7628, ENIG).
- L1 parts/signals · L2 solid GND · L3 3.3 V plane with a solid ground island under the radar ·
  L4 radar, 80 MHz oscillator, level translator, LED.
- Radar BGA (0.5 mm pitch, 0.275 mm pads per Infineon UG091722) fanned out in two staggered
  via rows; nothing but ground under the chip on the inner layers.
- Each of the radar's seven supply domains is a straight 0.3 mm lane from its ball through
  100 nF → 1 µF → 10 µF → ferrite, fed by a low-noise 7 µVrms LDO (Infineon's π-filter
  scheme, with the small capacitor closest to the ball).
- Radar SPI/control moved to the module's bottom pad row so the level translators sit right
  between the MCU and the radar; translators split over both faces so no radar line crosses.
- Module at the board edge with the antenna keep-out of its datasheet on every layer; the
  60 mm ground plane is exactly the width Silicon Labs recommends for the built-in antenna.
- Every ground and 3.3 V pad has its own via to its plane.
- Checked: ERC/DRC clean, schematic↔PCB parity, pin maps against the datasheets, BOM/CPL
  against the board, and a FreeCAD interference check of the real board STEP against the
  enclosure, lid clamps and radome.

**Open source**
Schematic, PCB, enclosure (FreeCAD), firmware (C, tested against a Python reference) and the
radar simulation/ML pipeline: https://github.com/techmiguel/stillpoint (CERN-OHL-S-2.0).

## Licence

CERN-OHL-S-2.0

## Tags

radar, mmwave, 60ghz, matter, thread, presence-sensor, fall-detection, privacy, smart-home, bga

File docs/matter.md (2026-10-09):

# Matter data model

Goal: Home Assistant (and any Matter controller) sees the essentials **through standard
clusters**, with no custom integration. What Matter does not standardize goes into a
manufacturer cluster that the user may ignore.

## Transport

- Thread, FTD device able to act as a router (mains powered: it strengthens the mesh).
- Commissioning over BLE with the QR / manual code printed on the enclosure.
- No account, no cloud. In v1 the room configuration (zones, doors, height) is set over
  UART/USB with `tools/room_cfg.py` (JSON → v1 block validated with a CRC, stored in
  NVM3); configuration through the manufacturer cluster is planned for v2.

## Endpoints

| EP | Device type | Cluster | Attribute / event | Meaning |
|---|---|---|---|---|
| 0 | Root Node | Basic Information, OTA Requestor, … | — | standard |
| 1 | Occupancy Sensor | Occupancy Sensing (0x0406) | `Occupancy` | someone in the room (including still people) |
| 2–4 | Occupancy Sensor | Occupancy Sensing | `Occupancy` | occupancy per configured zone (e.g. bed, sofa, bathroom) |
| 5 | Contact Sensor | Boolean State (0x0045) | `StateValue` + `StateChange` event | **fall** (confirmed **or** uncertain) |
| 6 | Contact Sensor | Boolean State | `StateValue` | **uncertainty**: some output is "uncertain" |
| 1 | — | manufacturer cluster 0xFFF1FC01 ([stillpoint_cluster.xml](../firmware/port/efr32mg26/stillpoint_cluster.xml)) | `PersonCount`, `FallState` (0 none, 1 suspected, 2 confirmed, 3 uncertain), `Uncertain`, `ProposedExclusions`, `ContractVersion`, `ModelHash` (model CRC32) | detail for advanced integrations |

Notes:

- From Matter 1.3 the Occupancy Sensing cluster declares the sensor type; it is declared
  as **radar**. Confirm the exact cluster revision supported by the chosen SDK.
- Matter has no "fall detector" device type. Boolean State is used because every
  controller shows and automates it; the endpoint label (Fixed Label / User Label) says
  "Fall". To be revisited if the specification adds something specific.
- Endpoint 5 fires on both confirmed and uncertain falls: a fall that cannot be verified
  **is reported**. The exact type is in the manufacturer cluster and on endpoint 6.
- `Tracks[]` (id, x, y, posture, state per person) is planned for v2: a list of structs
  needs a ZAP type definition and its Thread reporting cost is evaluated in F2. In v1
  individual positions only leave the device through the UART diagnostic stream.
- Risk R7: Home Assistant may not expose the manufacturer cluster without specific
  support. The person count is then only available per zone. Checked in F2 with the
  current python-matter-server.

## Reporting policy

- `Occupancy`: immediately when it becomes occupied; when it becomes empty, as soon as the
  last track is dropped (door: ~2 s). No extra fixed hold time.
- Fall: event when it becomes confirmed/uncertain; cleared after the person has been up
  for 5 s or by a local command.
- At most 2 reports/s per endpoint to keep the Thread mesh quiet; a new fall alarm
  bypasses the limit.

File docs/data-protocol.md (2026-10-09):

# Data protocol

## Principles

1. Nobody is recorded without written consent signed before the session (template
   [below](#consent-form-template)). Consent can be withdrawn at any time.
2. The radar captures no image and no voice. The data is still treated as personal: it is
   stored under a pseudonymous ID (`S07`), never a name.
3. The table linking IDs to people is kept apart, encrypted, and only the data owner can
   read it.
4. Training, validation and test are split **by person and by room** with
   [split.py](../ml/radarref/split.py); sessions that would mix them are discarded.
   Without this no metric means anything.
5. Falls are **simulated by healthy adults** on a crash mat. This limitation is written
   next to every published fall metric: real falls of older people are slower, more varied
   and often without recovery, and may behave differently.

## What is recorded per session

| File | Content |
|---|---|
| `*.rfad` | ADC frames from the kit (F1–F3 only), written by `ml/capture_kit.py` |
| `*.json` | session metadata: pseudonym, room, mounting height, time, radar configuration, firmware and contract versions |
| `features/*.bin` | contract v1 records (66 bytes per track and frame) |
| `truth.csv` | ground truth from `bench/annotator.py` |

## Labelling without a camera

In private rooms (bathroom, bedroom) no camera is used. Labelling follows a timed script:
an operator logs every change with a key-press app synced over NTP
(`bench/annotator.py`). In a lab room, with specific consent, a camera may be used only to
verify labels; those videos never leave the labelling team and are deleted once checked.

## Session script (≈ 25 min)

| Block | Activities | Repetitions |
|---|---|---|
| Presence | enter, walk, stand, sit still for 3 min, leave | 3 |
| Posture | standing ↔ sitting ↔ lying (sofa, bed, floor) | 3 each |
| Confusers | sit down hard, lie down fast on the bed, crouch to pick something up, tie shoelaces, exercise | 3 each |
| Falls | forward, backward, sideways, from sitting, slow slip; on the mat | 2 each (10 per session) |
| Two people | one still, the other walks in front and stops; crossing | 3 |

Mind the numbers: because of the split by person and room, the ≥ 100 falls of criterion F1
must come **from the test split only**. Example: 4 test people × 3 sessions × 10 falls in
the test room = 120 falls; the other 8 people record in the other 3 rooms for training and
validation (≈ 160–240 falls).

## Public datasets

Used only for prototyping (signal shapes, model architecture), after checking their
licence. They cannot give the final model because they use other radars, frequencies and
mountings; no published metric comes from them.

## Consent form template

> Starting template, not legal advice: have it reviewed before use and fill in the data
> controller.

**Project:** 60 GHz radar presence and fall sensor (research prototype).
**Data controller:** ______________________ · Contact: ______________________

**What is recorded.** A 60 GHz radar measures distances and movement inside the room.
**It records no image and no sound.** The radar signals are stored with the time and what
you are doing at each moment according to the script (for example "sitting",
"simulated fall").

**Why.** To train and measure the sensor. If you agree below, an anonymized version may be
published so others can check the results.

**Simulated falls.** You will be asked to let yourself fall in a controlled way onto a
crash mat. You may refuse any exercise without giving a reason. Do not take part if you
have an injury, a balance problem, are pregnant or have any other condition that advises
against it.

**Your rights.**
- Taking part is voluntary. You may withdraw at any time and ask for your data to be
  deleted, except data already published anonymously.
- Your data is identified by a code, never by your name.
- Retention: until the end of the project or ___ years, whichever comes first.
- You can exercise access, rectification, erasure, objection and restriction by writing to
  the contact above, and complain to the data protection authority.

**Permissions (tick the ones you accept)**

- [ ] I agree to take part in the recording sessions.
- [ ] I agree to the simulated falls on a crash mat.
- [ ] I agree that my **anonymized** radar data may be published.
- [ ] I agree that, in the lab room only, a camera may be used to verify labels, deleted after verification.

Name: ______________________ Signature: ______________ Date: ___/___/______

Assigned code (filled in by the team): S___

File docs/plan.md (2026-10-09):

# Plan and risks

Each phase ends at a gate with a verifiable criterion. A phase does not start until the
previous one is closed.

| Phase | Content | Exit gate | Status |
|---|---|---|---|
| **F0** Definition | scope, numeric criteria, contract v1, interfaces, consent, reference chain in simulation | documents reviewed; tests green | **done (2026-10-05)** |
| **F1** Kit + PC | BGT60TR13C evaluation kit over USB; capture with Infineon's radar SDK; run `radarref` on real data; tune CFAR, breathing thresholds and interferer learning | P1, P2, P4 met *offline* in 2 rooms | tools ready; capture pending |
| **F2** Embedded kit | EFR32MG26 kit + radar board over SPI; port DSP, tracking and decision; Matter with HA; measure cycles and RAM; ≥ 7-day comparison against an Aqara FP2 | **kill criterion** (P1, P2, P3 ≥ reference); compute budget ≤ 50 % | firmware written and tested on PC; SDK build pending |
| **F3** Data and model | consented campaign: ≥ 12 people, ≥ 4 rooms, ≥ 150 simulated falls on a mat; retrain on real data; split by person and room | A1, A2, F1, F4 on the test split | pending |
| **F4** Own board rev A | schematic and PCB, radome from coupons, enclosure; bring-up | contract records match the kit's on the same scenario; S3–S5 | **designed and verified; order after F2** |
| **F5** Final bench | 30 sensor-days of daily life, scripted scenarios, comparison with the reference | every criterion in [requirements](requirements.md#acceptance-criteria-v1) | pending |
| **F6** Publication | metrics report with CIs, anonymized bench data, open design | — | pending |

## Done ahead of the hardware

Everything that can be written and checked on a PC has been done, so the phases that need
hardware start by measuring instead of programming. None of this closes a gate: gates
need real measurements.

| Phase | Done | How it was checked | Still needed for the gate |
|---|---|---|---|
| F0 | Python reference chain: FMCW simulator, two-path DSP, tracking with room logic, contract, int8 classifier, decision; regression scenarios for the known failures | `ml/tests` | — |
| F1 | `ml/capture_kit.py` (capture with the Infineon SDK, same conversion as the firmware), `bench/` (annotation, events, Home Assistant export, report with CIs) | `ml/tests/test_bench.py`, demo report in [img/bench_demo](img/bench_demo/report.md) | captures in 2 real rooms |
| F2 | Complete C firmware (DSP, tracking, int8 inference, decision, application) identical to Python; EFR32MG26 port (driver, Matter with a manufacturer cluster, COBS diagnostics, room configuration in NVM3) | C ↔ Python equivalence end to end with gcc and clang, ASan/UBSan; the port is only syntax-checked against SDK stub headers | build with the Simplicity SDK, measure cycles and RAM, 7 days against an Aqara FP2 |
| F4 | Rev A schematic and 4-layer PCB, placed and routed, with fabrication files; enclosure, lid, λ/2 radome and coupon in FreeCAD | ERC/DRC clean, no schematic/PCB differences, `kicadverify verify` PASS; `mechanical/enclosure.py` assertions with the real board STEP | order after F2 ([hardware](hardware.md)) |

CI (`.github/workflows/ci.yml`) runs the firmware tests with gcc and clang and the
C ↔ Python equivalence under sanitizers on every push.

## Material for F1–F2

| Item | Use |
|---|---|
| Infineon BGT60TR13C evaluation kit with USB base board | real frames on the PC |
| Silicon Labs EFR32MG26 development kit | embedded DSP, Matter/Thread |
| Thread border router (HA with Matter Server + Thread adapter) | commissioning and bench |
| Aqara FP2 | commercial reference on the bench |
| Crash mat ≥ 5 cm | fall protocol |
| Standing fan, mirror ≥ 1 m², curtain | ghost scenarios |

## Risks and known limitations

| ID | Risk / limitation | Probability | Impact | Mitigation | Status |
|---|---|---|---|---|---|
| R1 | The simulator is optimistic: real breathing is weaker and multipath more complex | high | high | F1 with real data before any fine tuning; no synthetic metric is published | open |
| R2 | Fixed interferers (fan) count as a person until learned (20 s in simulation) | medium | medium | persist learned zones; manual excluded zones; measure in G1–G2 | open |
| R3 | Two still people at the same range (±6 cm) give a single breathing detection with a blended angle | medium | medium | room logic keeps both static tracks; documented; more chirps/RX in v2 | accepted for v1 |
| R4 | Identity swaps when two people cross | medium | low for count, medium for posture | association penalty between a still track and a fast measurement; swap metric on the bench | partly mitigated |
| R5 | The EFR32MG26 MVP or RAM is not enough for DSP + Matter | medium | high | measure in F2; plan B (PSoC Edge E84 + EFR32MG24 RCP) | open |
| R6 | Lying on a high or low bed mistaken for a fall | medium | high | height rule (0.55 m) + a configurable "bed" zone where lying is not a fall; scenario A3 | open |
| R7 | Home Assistant does not expose the manufacturer cluster (count, postures) | high | medium | essentials in standard clusters; count per zone; follow Matter's evolution | open |
| R8 | Simulated falls ≠ real falls of older people | certain | high | stated next to every metric; include slow falls and falls from sitting; never presented as a medical device | accepted |
| R9 | A printed radome detunes the radar (thickness, humidity, pigments) | medium | medium | thickness coupons measured with the kit; natural PETG, 100 % infill | open |
| R10 | Plastic next to the module antenna detunes 2.4 GHz | medium | medium | measure RSSI with and without the enclosure; thin the wall in that sector if more than 3 dB is lost | open |
| R11 | Radar die temperature inside the closed enclosure | low | medium | ~60 mW average; read the internal sensor in the closed enclosure, keep it below 70 °C | open |
| R12 | MGM260P and KC2016 not stocked at JLCPCB | high | low | Global Sourcing or consigned parts; KC2016 alternative to be checked for ≤ 1 ps jitter | open |

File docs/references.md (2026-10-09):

# References

Datasheets and application notes used to design and check rev A. They belong to their
manufacturers and are linked, not copied. What each one was used for is in
[hardware.md](hardware.md#checked-against-the-datasheets).

| Part | Document | Used for |
|---|---|---|
| Infineon BGT60TR13C | [datasheet](https://www.infineon.com/dgdl/Infineon-BGT60TR13C-DataSheet-v02_49-EN.pdf) | ball map, supplies and noise, clock, VAREF, current, TX power |
| Infineon BGT60TR13C shield board | user manual UG091722 ([product page](https://www.infineon.com/cms/en/product/sensor/radar-sensors/radar-sensors-for-iot/60ghz-radar/bgt60tr13c/)) | land pattern (fig. 5c), π filters per domain (§3.3, fig. 6), oscillator and its series resistor (§3.4) |
| Silicon Labs MGM260P | [datasheet](https://www.silabs.com/documents/public/data-sheets/mgm260p-datasheet.pdf) | ordering code, pinout, land pattern, antenna keep-out, current |
| Silicon Labs CP2102N | [datasheet](https://www.silabs.com/documents/public/data-sheets/cp2102n-datasheet.pdf) | self-powered connection, RSTb, VBUS sense |
| TI SN74AVC4T245 | [datasheet](https://www.ti.com/lit/ds/symlink/sn74avc4t245.pdf) | pinout, DIR/OE, unused inputs |
| TI TPS7A20 | [datasheet](https://www.ti.com/lit/ds/symlink/tps7a20.pdf) | noise, pinout |
| TI TLV757P | [datasheet](https://www.ti.com/lit/ds/symlink/tlv757p.pdf) | WSON-6 land pattern, dropout |
| Kyocera KC2016 | [datasheet](https://media.digikey.com/pdf/Data%20Sheets/AVX%20PDFs/KC2016K80.0000C1GECN.pdf) | 80 MHz, 1.8 V, phase jitter |
| ST USBLC6-2 | [datasheet](https://www.st.com/resource/en/datasheet/usblc6-2.pdf) | pinout |
| G-Switch GT-USB-7051A | [drawing](https://datasheet.lcsc.com/lcsc/2108072030_G-Switch-GT-USB-7051A_C2843970.pdf) | land pattern and height |
| Tag-Connect TC2030 | [drawing](https://www.tag-connect.com/wp-content/uploads/bsk-pdf-manager/TC2030-CTX_1.pdf) | footprint |
| Infineon sensor-xensiv-bgt60trxx | [driver (Apache-2.0)](https://github.com/Infineon/sensor-xensiv-bgt60trxx) | firmware port |

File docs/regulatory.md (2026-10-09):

# 60 GHz emission (Europe)

v1 does not go through certification, but **its emission parameters must stay inside
what is allowed**. This table is the design reference; before any sale it is checked
against the current versions of the documents cited.

| Reference | What it sets (summary) |
|---|---|
| Decision 2006/771/EC and amendments (SRD), ERC/REC 70-03 | non-specific short-range devices in 57–64 GHz: 100 mW (20 dBm) EIRP, with extra limits on output power and density |
| ETSI EN 305 550 | harmonised standard for SRDs in 40–246 GHz (measurement methods) |
| Directive 2014/53/EU (RED) | market access framework |

## How the design applies it

| Parameter | Design limit | v1 value | Enforced in |
|---|---|---|---|
| Occupied band | inside 57.0–64.0 GHz | 60.0–61.25 GHz | `RadarConfig.check_eu`, `rf_radar_check_eu` |
| EIRP | ≤ 20 dBm | target 10 dBm (≥ 10 dB margin) | same; the BGT60 TX power is set to the lowest level that meets P1 |
| Duty cycle | < 100 % | 11 % | same |

- The radar configuration lives in firmware and cannot be changed over Matter; any
  configuration that fails the check is rejected and the radar is not started (fail safe).
- The BGT60TR13C is sold for this band. Its datasheet gives a maximum TX power of
  +5 dBm and an antenna gain of 3.5 dBi typical (5 dBi max): **≈ 10 dBm EIRP at most**.
  The estimate and a rough measurement (power meter or analyser with a 60 GHz horn, if
  available) are documented in F4 (criterion S4).
- The radome must not focus the beam: a flat λ/2 slab, no lenses.

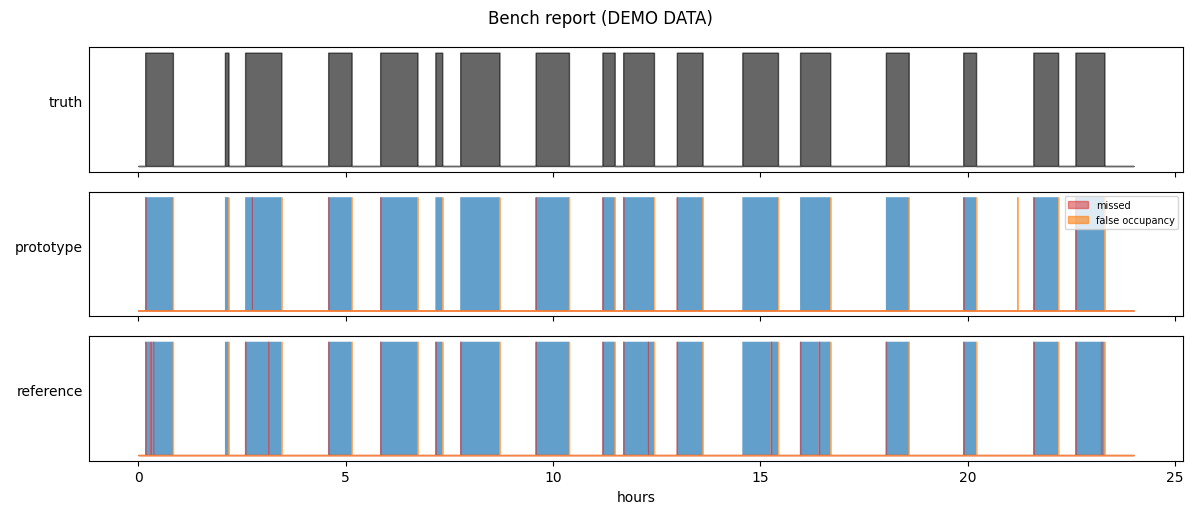
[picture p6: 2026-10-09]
docs/img/bench_demo/report.png

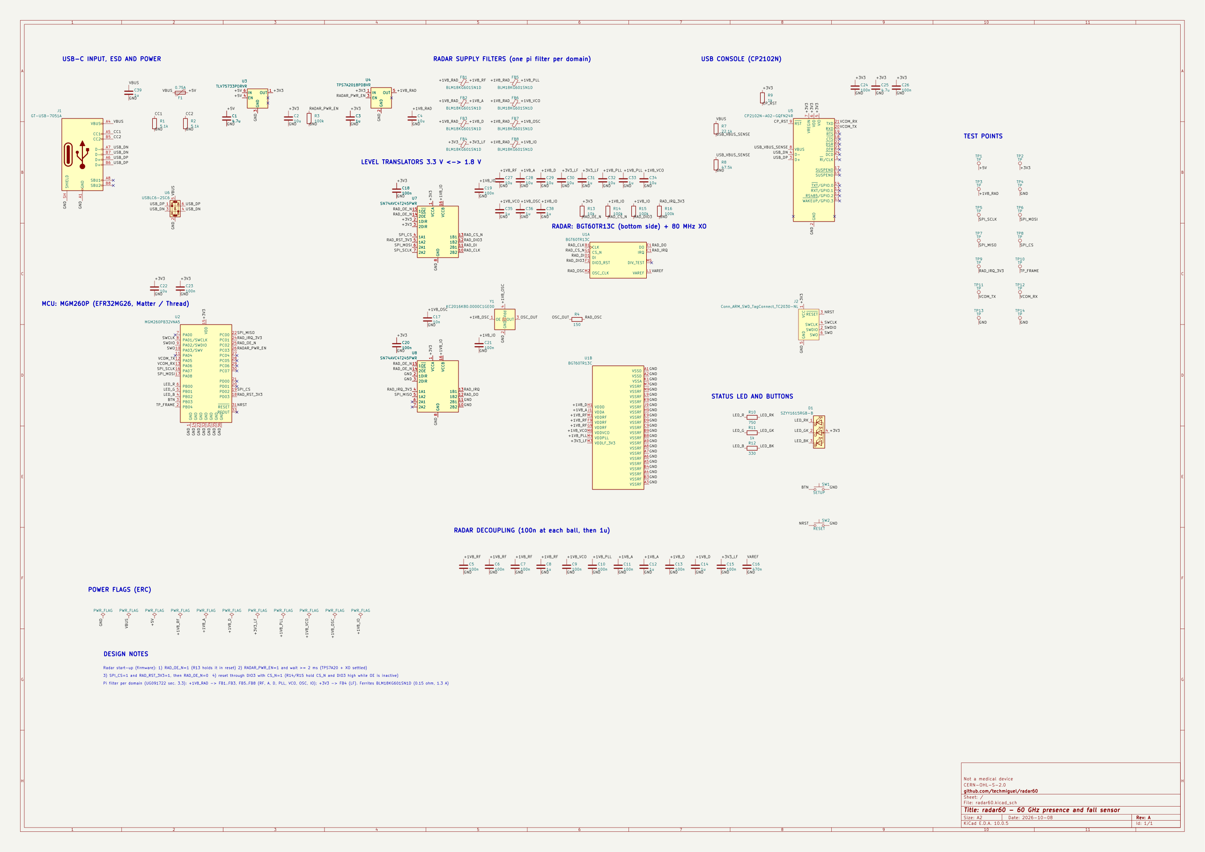
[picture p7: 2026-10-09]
docs/img/schematic.png

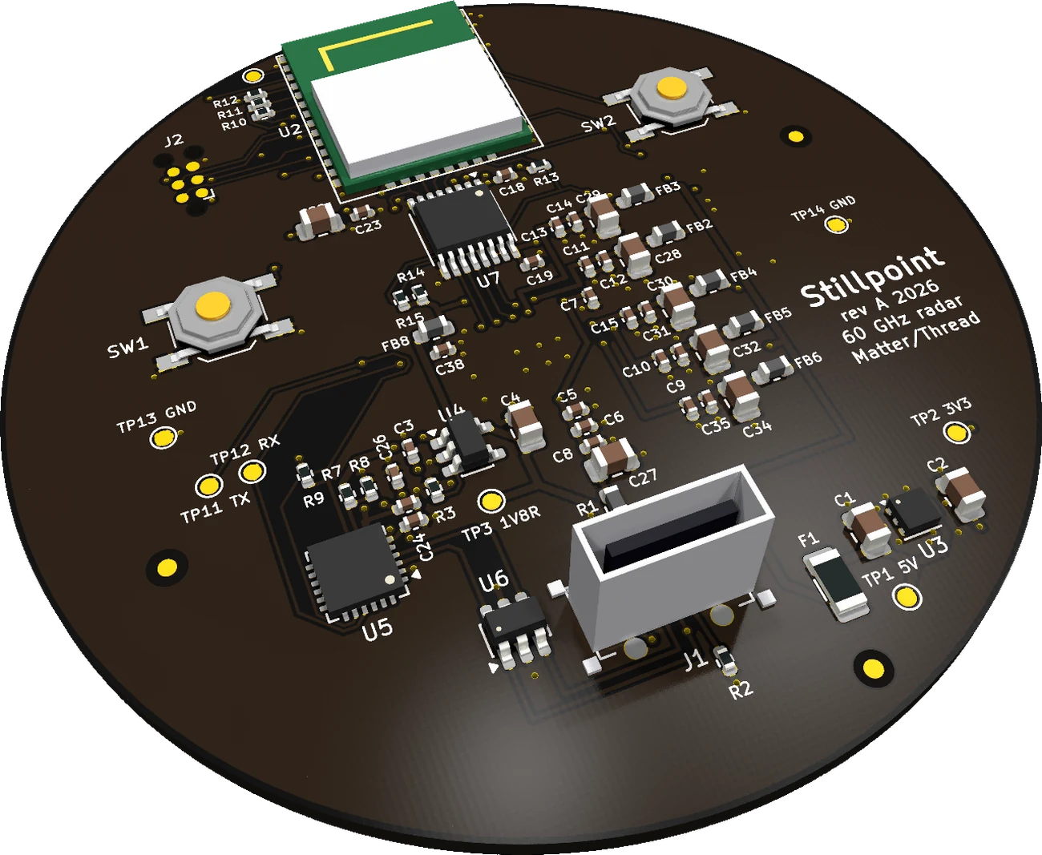
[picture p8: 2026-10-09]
docs/share/iso_top.webp

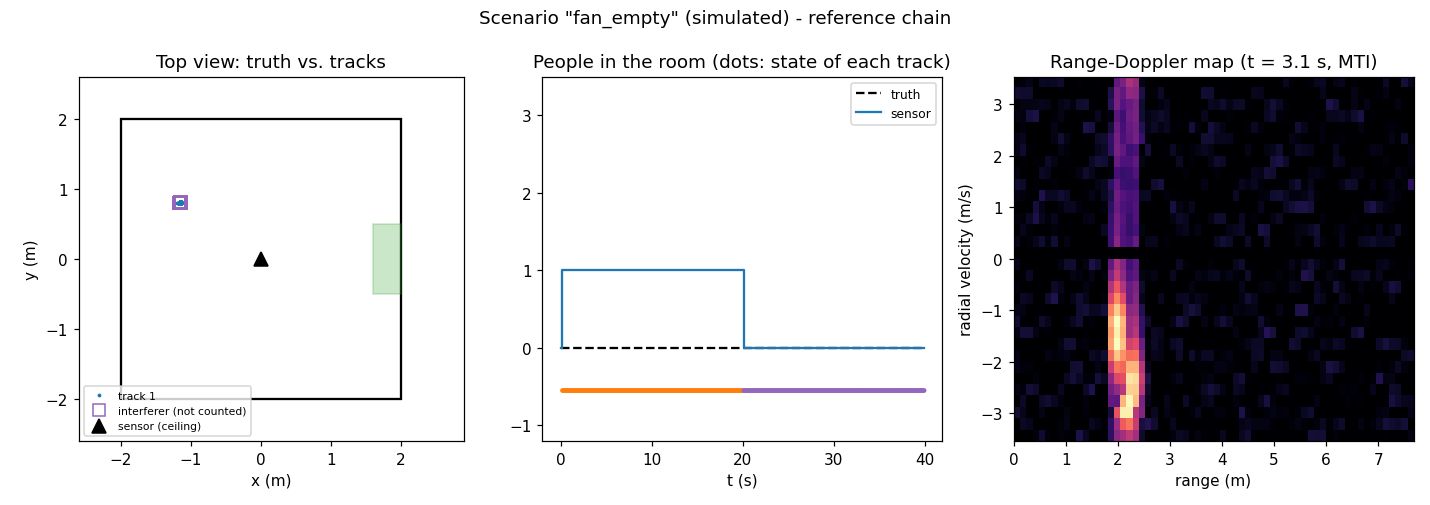
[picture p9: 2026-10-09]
docs/img/scenario_fan_empty.png

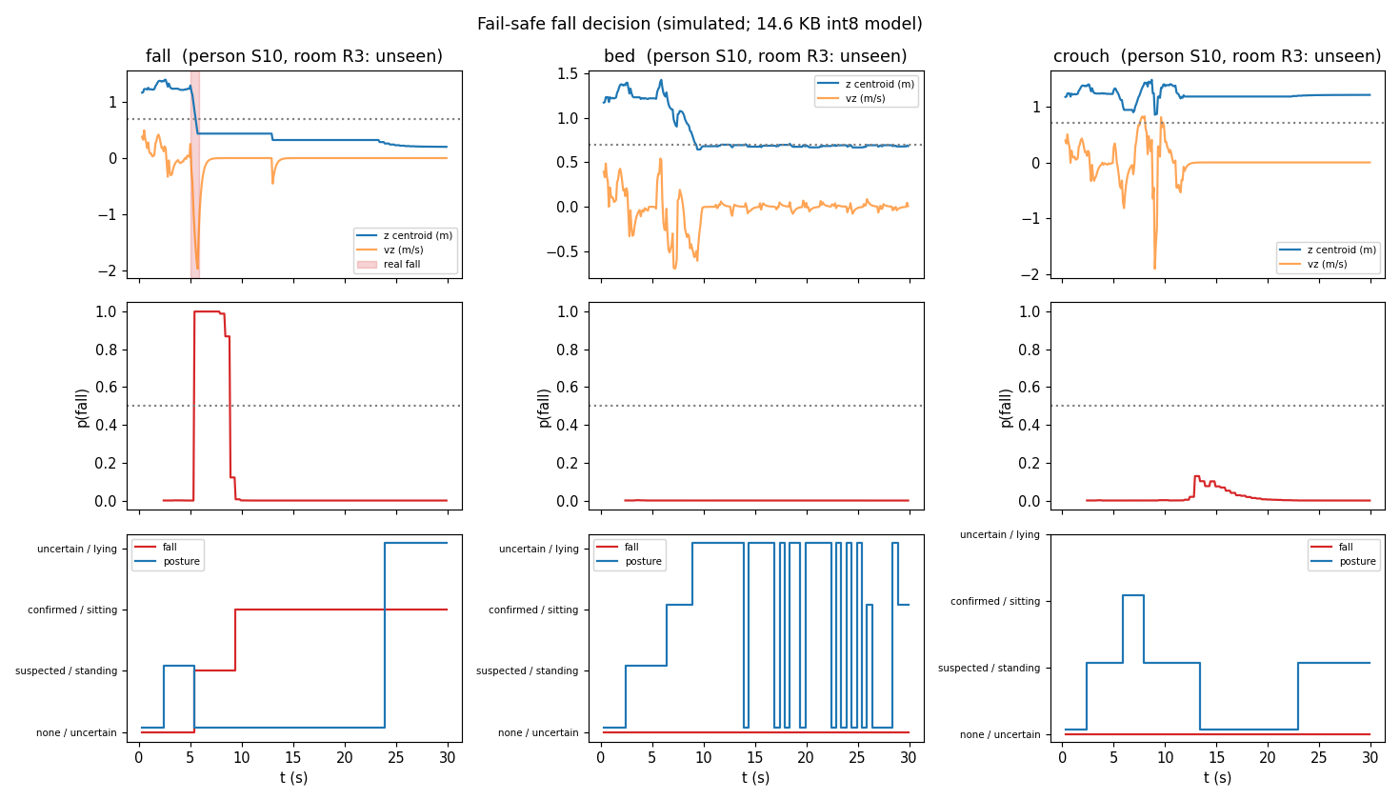
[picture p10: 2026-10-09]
docs/img/fall_events.png

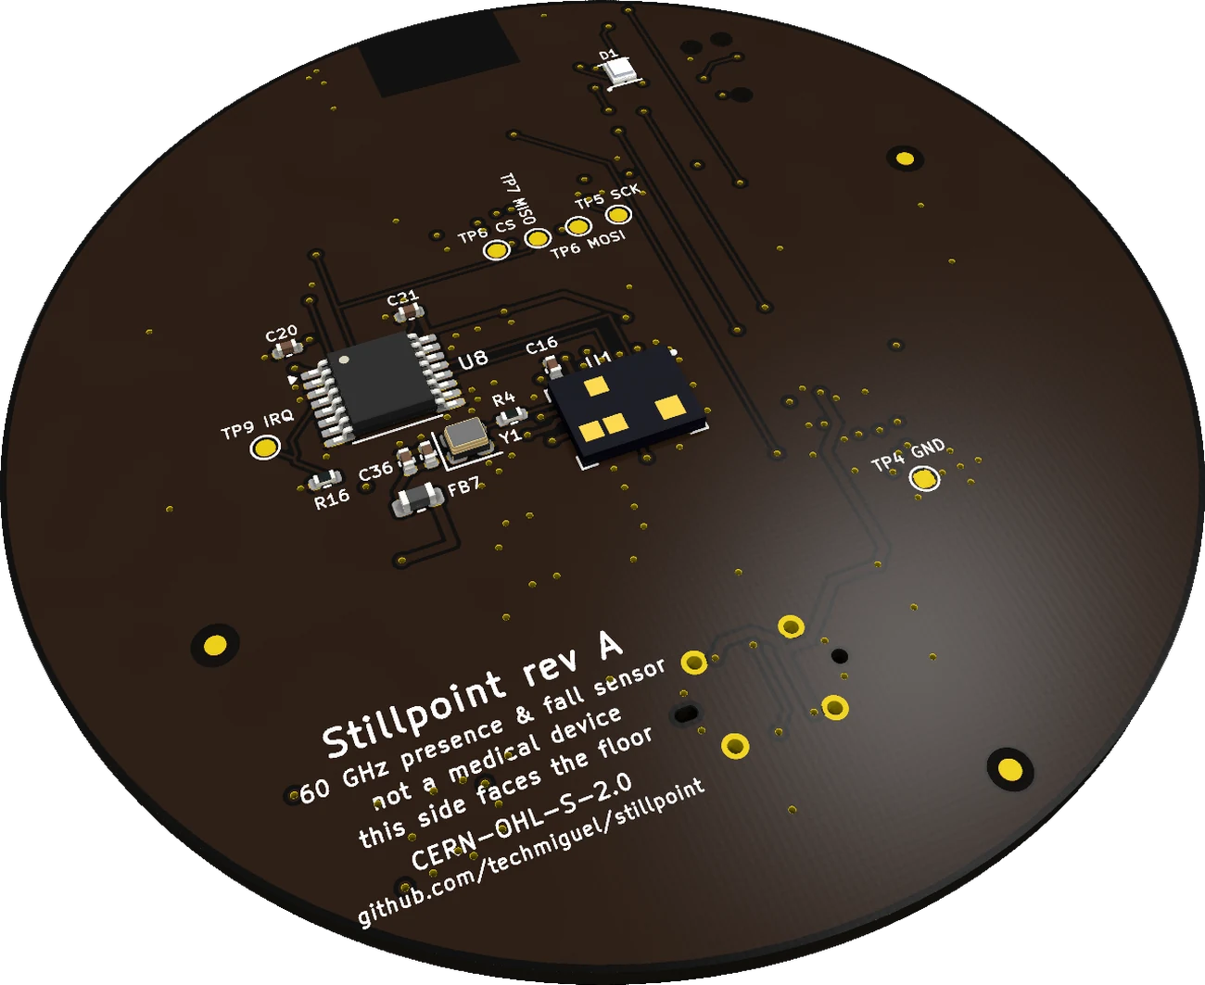
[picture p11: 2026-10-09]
docs/share/iso_bot.webp

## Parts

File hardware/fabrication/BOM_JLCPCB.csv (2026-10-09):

Comment | Designator | Footprint | LCSC Part # | Manufacturer | MPN | Qty
4.7u | C1 | C_0805_2012Metric | C1779 | Samsung | CL21A475KAQNNNE | 1
10u | C2,C4,C22,C27,C28,C29,C30,C32,C34 | C_0805_2012Metric | C15850 | Samsung | CL21A106KAYNNNE | 9
1u | C3,C8,C12,C14,C31,C33,C35,C36,C38,C39 | C_0402_1005Metric | C52923 | Samsung | CL05A105KA5NQNC | 10
100n | C5,C6,C7,C9,C10,C11,C13,C15,C18,C19,C20,C21,C23,C24,C26 | C_0402_1005Metric | C1525 | Samsung | CL05B104KO5NNNC | 15
470n | C16 | C_0402_1005Metric | C527010 | YAGEO | CC0402KRX5R7BB474 | 1
10n | C17 | C_0402_1005Metric | C15195 | Samsung | CL05B103KB5NNNC | 1
4.7u | C25 | C_0402_1005Metric | C469468 | YAGEO | CC0402MRX5R6BB475 | 1
SZYY1615RGB-B | D1 | LED_RGB_1615_SZYY1615RGB-B | C3029071 | Yongyu Photoelectric | SZYY1615RGB-B | 1
0.75A | F1 | Fuse_1206_3216Metric | C545214 | PTTC | SMD1206P075TFT | 1
BLM18KG601SN1D | FB1,FB2,FB3,FB4,FB5,FB6,FB7,FB8 | L_0603_1608Metric | C85833 | Murata | BLM18KG601SN1D | 8
GT-USB-7051A | J1 | USB_C_Receptacle_G-Switch_GT-USB-7051A | C2843970 | G-Switch | GT-USB-7051A | 1
5.1k | R1,R2 | R_0402_1005Metric | C25905 | UNI-ROYAL | 0402WGF5101TCE | 2
100k | R3,R14,R15,R16 | R_0402_1005Metric | C25741 | UNI-ROYAL | 0402WGF1003TCE | 4
150 | R4 | R_0402_1005Metric | C25082 | UNI-ROYAL | 0402WGF1500TCE | 1
22.1k | R7 | R_0402_1005Metric | C43473 | UNI-ROYAL | 0402WGF2212TCE | 1
47.5k | R8 | R_0402_1005Metric | C25896 | UNI-ROYAL | 0402WGF4752TCE | 1
1k | R9,R11 | R_0402_1005Metric | C11702 | UNI-ROYAL | 0402WGF1001TCE | 2
750 | R10 | R_0402_1005Metric | C25132 | UNI-ROYAL | 0402WGF7500TCE | 1
330 | R12 | R_0402_1005Metric | C25104 | UNI-ROYAL | 0402WGF3300TCE | 1
10k | R13 | R_0402_1005Metric | C25744 | UNI-ROYAL | 0402WGF1002TCE | 1
SETUP | SW1 | SW_SPST_TL3342 | C2886898 | E-Switch | TL3342F160QG | 1
RESET | SW2 | SW_SPST_TL3342 | C2886898 | E-Switch | TL3342F160QG | 1
BGT60TR13C | U1 | Infineon_PG-VF2BGA-40-1_6.5x5mm_P0.5mm | C3606641 | Infineon | BGT60TR13CE6327XUMA1 | 1
MGM260PB32VNA5 | U2 | SiliconLabs_MGM260P_12.9x15mm |  | Silicon Labs | MGM260PB32VNA5 | 1
TLV75733PDRVR | U3 | WSON-6-1EP_2x2mm_P0.65mm_EP1x1.6mm | C2868428 | Texas Instruments | TLV75733PDRVR | 1
TPS7A2018PDBVR | U4 | SOT-23-5 | C963430 | Texas Instruments | TPS7A2018PDBVR | 1
CP2102N-A02-GQFN24R | U5 | QFN-24-1EP_4x4mm_P0.5mm_EP2.6x2.6mm | C969151 | Silicon Labs | CP2102N-A02-GQFN24R | 1
USBLC6-2SC6 | U6 | SOT-23-6 | C7519 | STMicroelectronics | USBLC6-2SC6 | 1
SN74AVC4T245PWR | U7,U8 | TSSOP-16_4.4x5mm_P0.65mm | C81461 | Texas Instruments | SN74AVC4T245PWR | 2
KC2016K80.0000C1GE00 | Y1 | Crystal_SMD_2016-4Pin_2.0x1.6mm | C1988243 | Kyocera AVX | KC2016K80.0000C1GE00 | 1

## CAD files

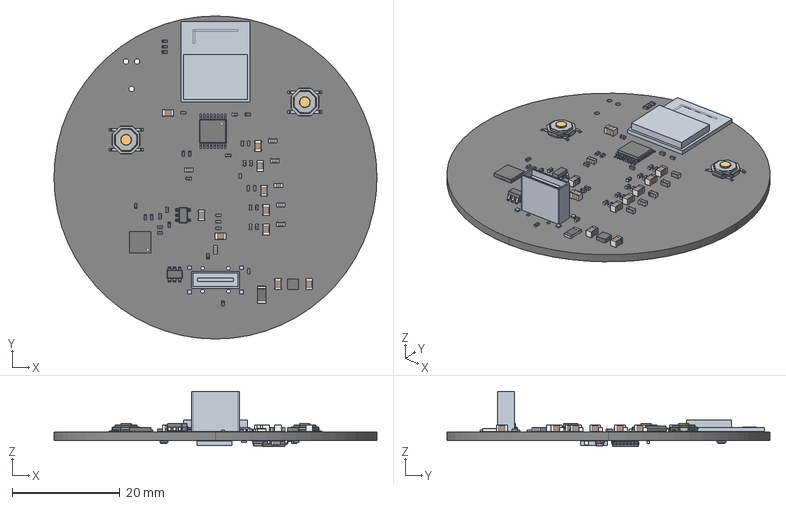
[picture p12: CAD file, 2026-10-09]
hardware/fabrication/stillpoint.step
60.0 x 60.0 x 10.3 mm
R_0402_1005Metric x 14
Fuse_1206_3216Metric
C_0402_1005Metric x 28
C_0805_2012Metric x 10
L_0603_1608Metric x 8
SOT-23-5
QFN-24-1EP_4x4mm_Pitch0.5mm
SW_SPST_TL3342 x 2
TSSOP-16_4.4x5mm_P0.65mm x 2
WSON_6_1EP_2x2mm_P065mm_EP1x16mm
SOT-23-6
Crystal_SMD_2016-4Pin_2.0x1.6mm
stillpoint_PCB

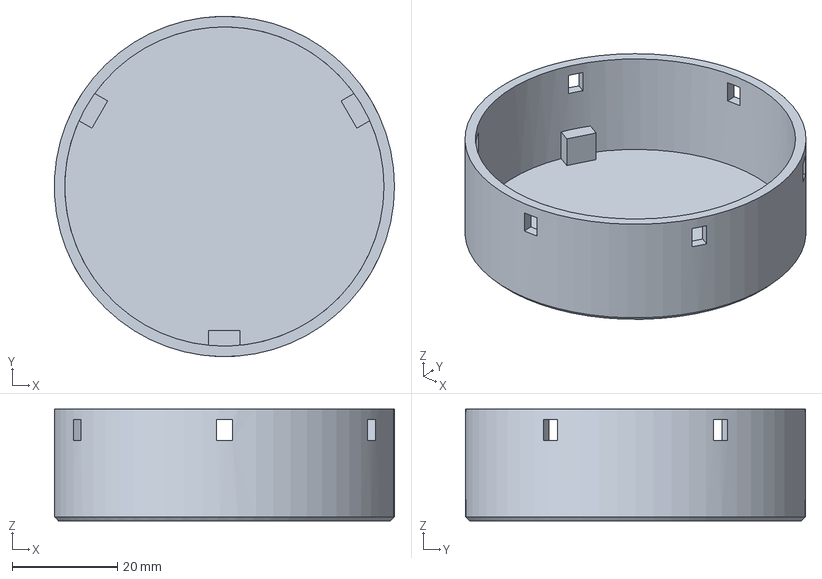
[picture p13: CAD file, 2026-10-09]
mechanical/cad/enclosure.step
64.8 x 64.8 x 21.3 mm

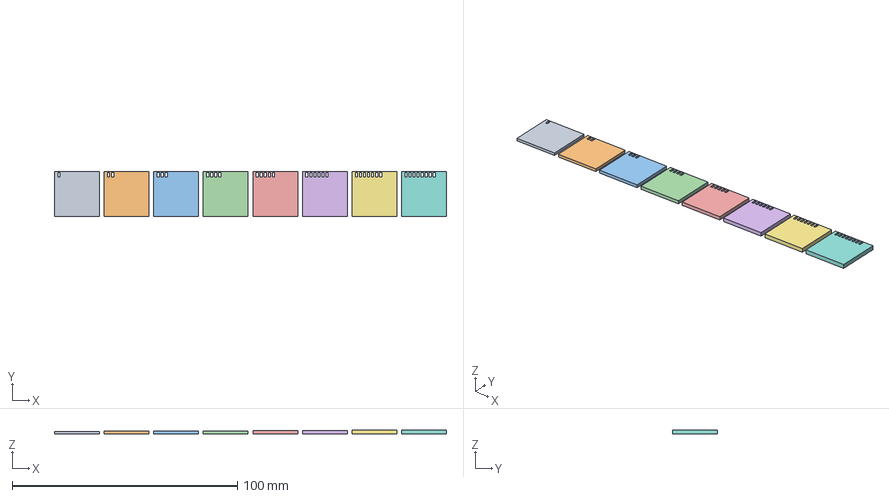
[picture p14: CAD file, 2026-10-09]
mechanical/cad/radome_coupon.step
174.0 x 20.0 x 1.90 mm

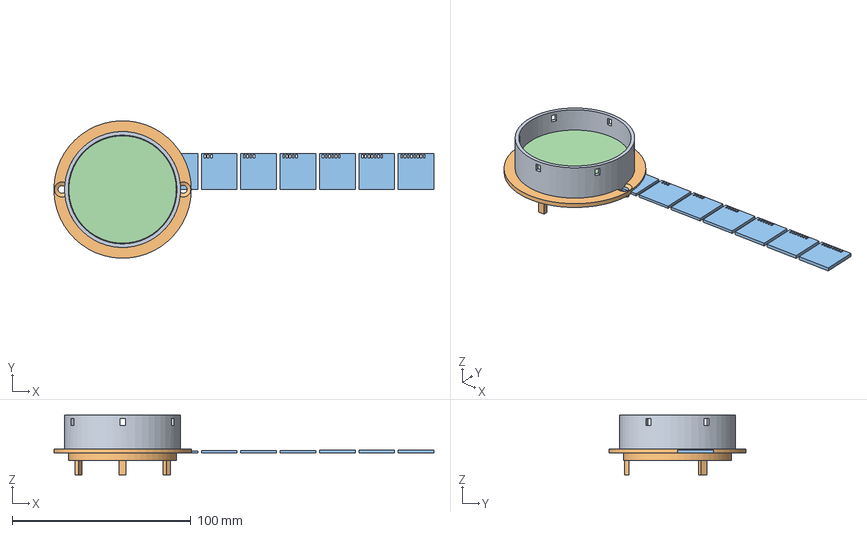
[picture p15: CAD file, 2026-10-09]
mechanical/cad/stillpoint.FCStd
212.3 x 76.8 x 33.5 mm
enclosure
lid
radome_coupon
board_reference
bgt60_reference

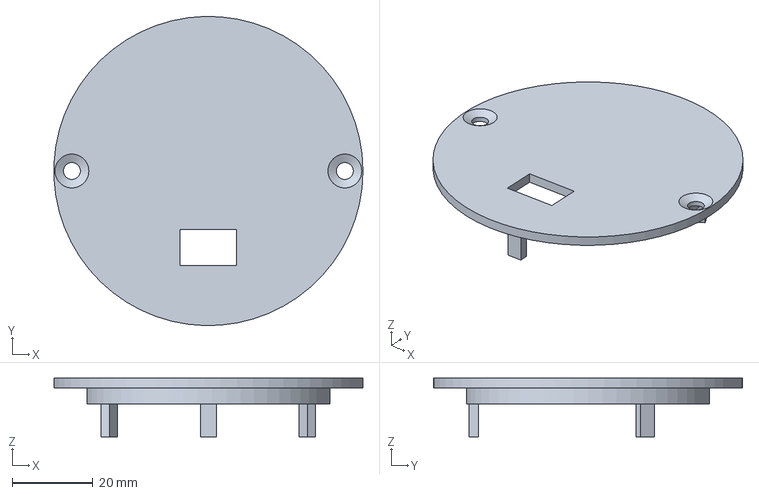
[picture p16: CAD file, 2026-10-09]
mechanical/cad/lid.step
76.7 x 76.8 x 14.6 mm

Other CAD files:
mechanical/cad/enclosure.stl
mechanical/cad/lid.stl
mechanical/cad/radome_coupon.stl

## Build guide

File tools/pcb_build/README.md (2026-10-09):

# tools/pcb_build

Scripts that build `hardware/stillpoint.kicad_pcb` from the schematic. The board is not
drawn by hand: placement and every critical route are written down here, so they can be
reviewed and repeated.

| Step | Script | What it does |
|---|---|---|
| 1 | `build.py` + `placement.py` | footprints from the schematic netlist (with MPN/LCSC), nets and the placement of every part |
| 2 | `zones.py` | planes (L2 GND, L3 +3V3 with a GND island under the radar), GND pours, antenna keep-out, enclosure support pads, stackup |
| 3 | `prerout.py` | radar BGA escape (two staggered via rows), IRQ/DO lanes to U8, oscillator, GND vias under the chip |
| 4 | `rails.py` | one straight lane per radar supply domain (via → 100 n → 1 µ → 10 µ → ferrite), +1V8_RAD bus, CP2102N |
| 5 | `jbreak.py` | vertical USB-C breakout (VBUS through the row gap, D-/D+ crossed) and the USB pair through the ESD part to the CP2102N |
| 6 | `gndvias.py` | one plane via per GND or +3V3 pad |
| 7 | `route.py` | Freerouting for the rest (export DSN, route, import SES) |
| 8 | `zones.py`, `finalize.py`, `dangling.py`, `c16fix.py`, `thermal.py` | refill pours, solid connection on U1/U2/U3/J1/J2, remove dangling vias, C16 ground, U3 thermal vias |
| 9 | `silk.py`, `legends.py` | reference designators that clear pads and other text, test-point labels, board legends |

All in one go: `sh tools/pcb_build/pipeline.sh`. The autorouter never touches the locked
items (fan-out, rails, USB).

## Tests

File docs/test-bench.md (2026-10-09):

# Test bench

It does two things: measure the [acceptance criteria](requirements.md#acceptance-criteria-v1)
and compare against a commercial sensor under the same conditions.

## Set-up

- A 4 × 4 m room with the door marked as an exit zone.
- Device under test (DUT) and an Aqara FP2 on the ceiling, ≤ 30 cm apart, with the same
  zone configuration.
- Both in the same Home Assistant: the FP2 through its local integration, the DUT over
  Matter. The HA history is exported to CSV (`bench/ha_export.py`).
- Ground truth: a script + a timestamping app on NTP time (`bench/annotator.py`).
- Floor marks every 0.5 m for the position error (P7).

## Scenarios

| ID | Scenario | Criteria |
|---|---|---|
| E1 | Enter, walk around, leave through the door | P4, P5, P6 |
| E2 | Sit still for 30 min (reading, screen) | P1 |
| E3 | Sleep / lie down for 2 h | P1, A2 |
| O1 | Still person; another walks in front | P2 |
| O2 | Still person; another stops in front for 30 s and leaves | P2 |
| G1 | Empty room with a standing fan on for 8 h | P3 |
| G2 | Empty room with a curtain moved by a fan | P3 |
| G3 | Mirror ≥ 1 m² on a wall; one person walks next to it | P6 |
| A3–A5 | Lie down fast on the bed, sit down hard, crouch | F4 |
| C1 | Simulated falls from the [session script](data-protocol.md#session-script--25-min) | F1, F3 |
| V1 | Daily life in a home, 30 sensor-days | F2, P3 |
| M1–M3 | Commissioning ×10, Thread router reboot, power cut | S1, S2 |

## Metrics

[metrics.py](../ml/radarref/metrics.py) and [bench/report.py](../bench/report.py) compute:

- Proportions (P1, F1…) with a Wilson interval.
- Rates per day (P3, F2) with an exact Poisson interval. With 0 events the report says
  "0 in N days; 95 % upper bound 3.69/N per day", never "no false alarms".
- Latencies as p50/p95, pairing each event with the first detection.

A synthetic demo of the report (made-up devices, to test the tool) is in
[img/bench_demo/report.md](img/bench_demo/report.md).

## Published report

For every criterion: DUT value, reference value, n, interval, pass/fail, and the
limitations (simulated falls, one room, mounting height). Failures and the scenarios
where the reference wins are published too.

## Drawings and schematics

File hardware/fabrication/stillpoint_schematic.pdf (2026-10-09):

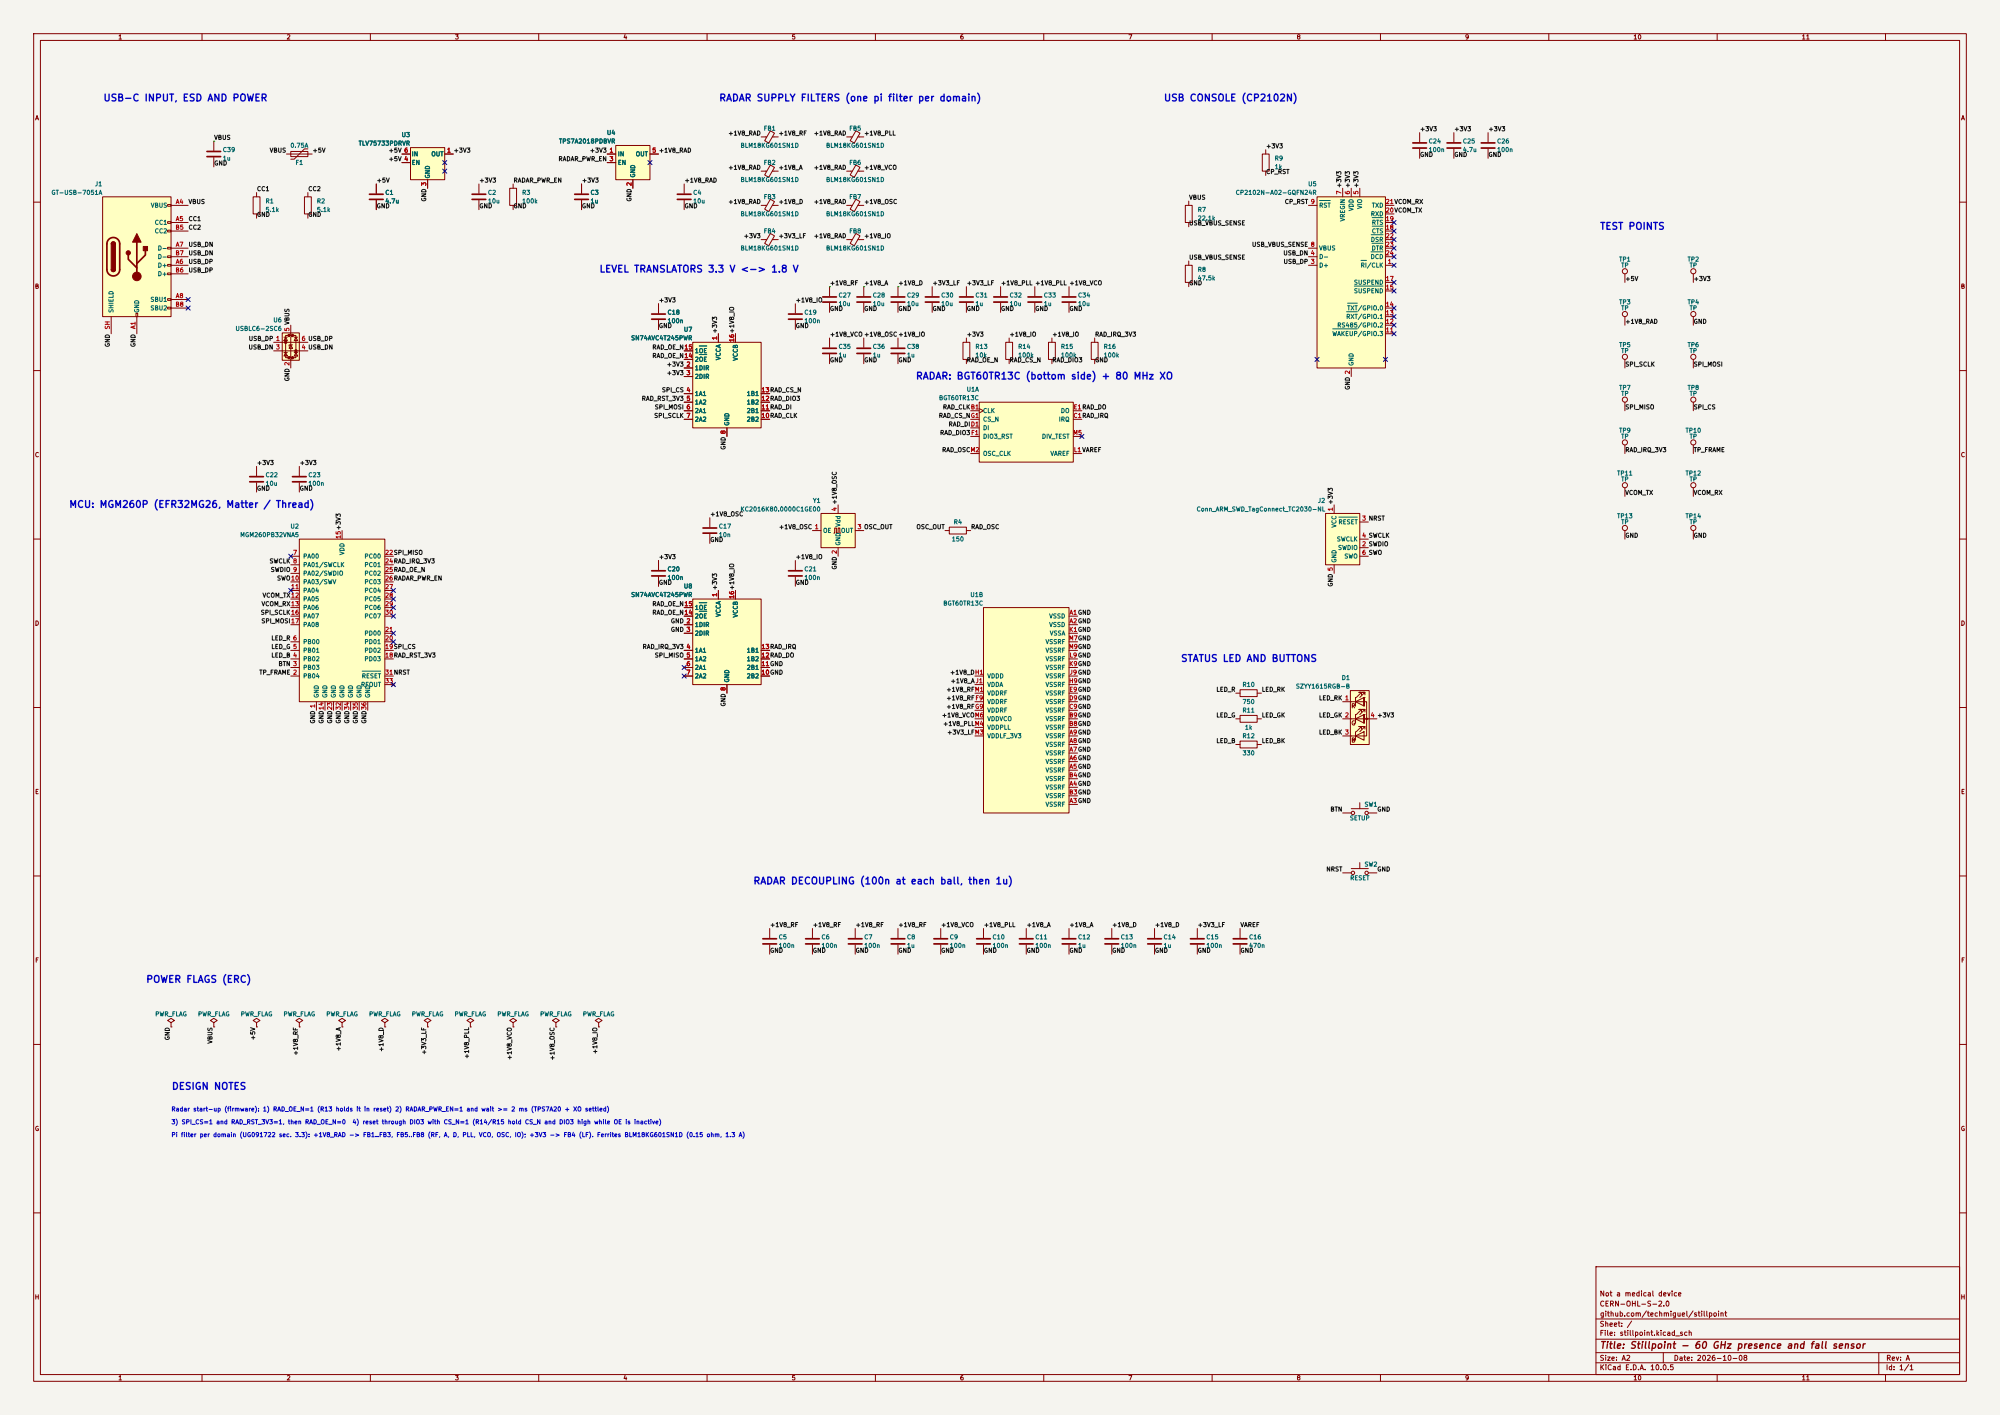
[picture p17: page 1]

USB-C INPUT, ESD AND POWER

RADAR SUPPLY FILTERS (one pi filter per domain)
SPI_MOSI SPI_SCLK +3V3 +3V3 RADAR_PWR_EN

GND
RADAR: BGT60TR13C (bottom side) + 80 MHz XO

1 PB04 2 PB03 3 PB02 4 PB01 5 PB00 6 PA00 7 PA01/SWCLK 8 PA02/SWDIO 9 PA03/SWV 10 PA04 11 PA05 12 PA06 13 GND 14 VDD 15 PA07 16 PA08 17 PD03 18 PD02 19 PD01 20 PD00 21 PC00 22 GND 23 PC01 24 PC02 25 PC03 26 PC04 27 PC05 28 PC06 29 PC07 30 RESET 31 GND 32 RFOUT 33 GND 34 GND 35 GND 36 U2 MGM260PB32VNA5

RADAR DECOUPLING (100n at each ball, then 1u)

Radar start-up (firmware): 1) RAD_OE_N=1 (R13 holds it in reset) 2) RADAR_PWR_EN=1 and wait >= 2 ms (TPS7A20 + XO settled)

3) SPI_CS=1 and RAD_RST_3V3=1, then RAD_OE_N=0 4) reset through DIO3 with CS_N=1 (R14/R15 hold CS_N and DIO3 high while OE is inactive) Pi filter per domain (UG091722 sec. 3.3): +1V8_RAD -> FB1..FB3, FB5..FB8 (RF, A, D, PLL, VCO, OSC, IO); +3V3 -> FB4 (LF). Ferrites BLM18KG601SN1D (0.15 ohm, 1.3 A)

Not a medical device
CERN-OHL-S-2.0
github.com/techmiguel/stillpoint
Sheet: /
File: stillpoint.kicad_sch
Title: Stillpoint - 60 GHz presence and fall sensor

Size: A2 | Rev: A
KiCad E.D.A. 10.0.5 | Id: 1/1

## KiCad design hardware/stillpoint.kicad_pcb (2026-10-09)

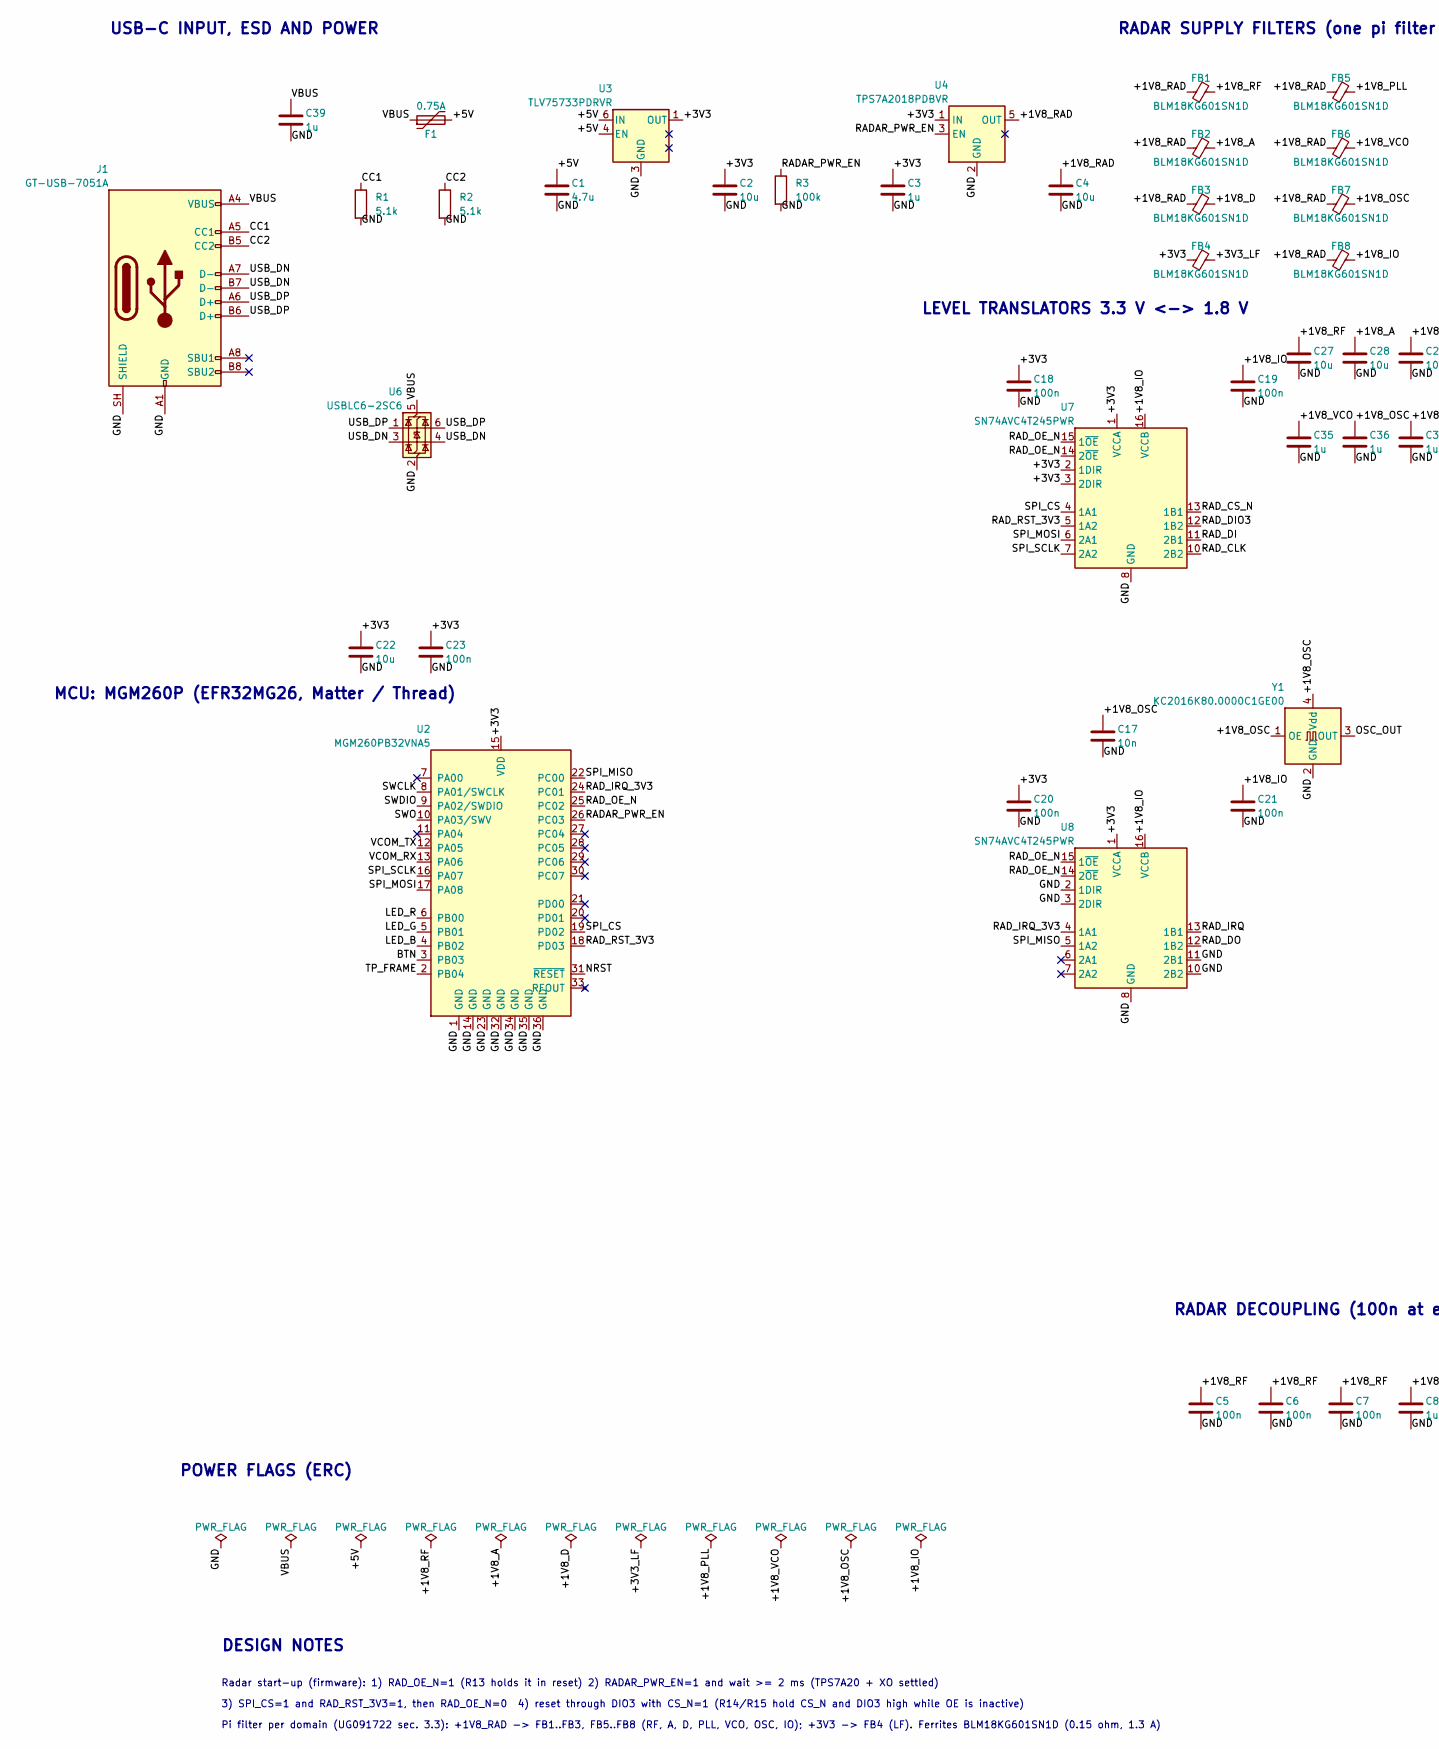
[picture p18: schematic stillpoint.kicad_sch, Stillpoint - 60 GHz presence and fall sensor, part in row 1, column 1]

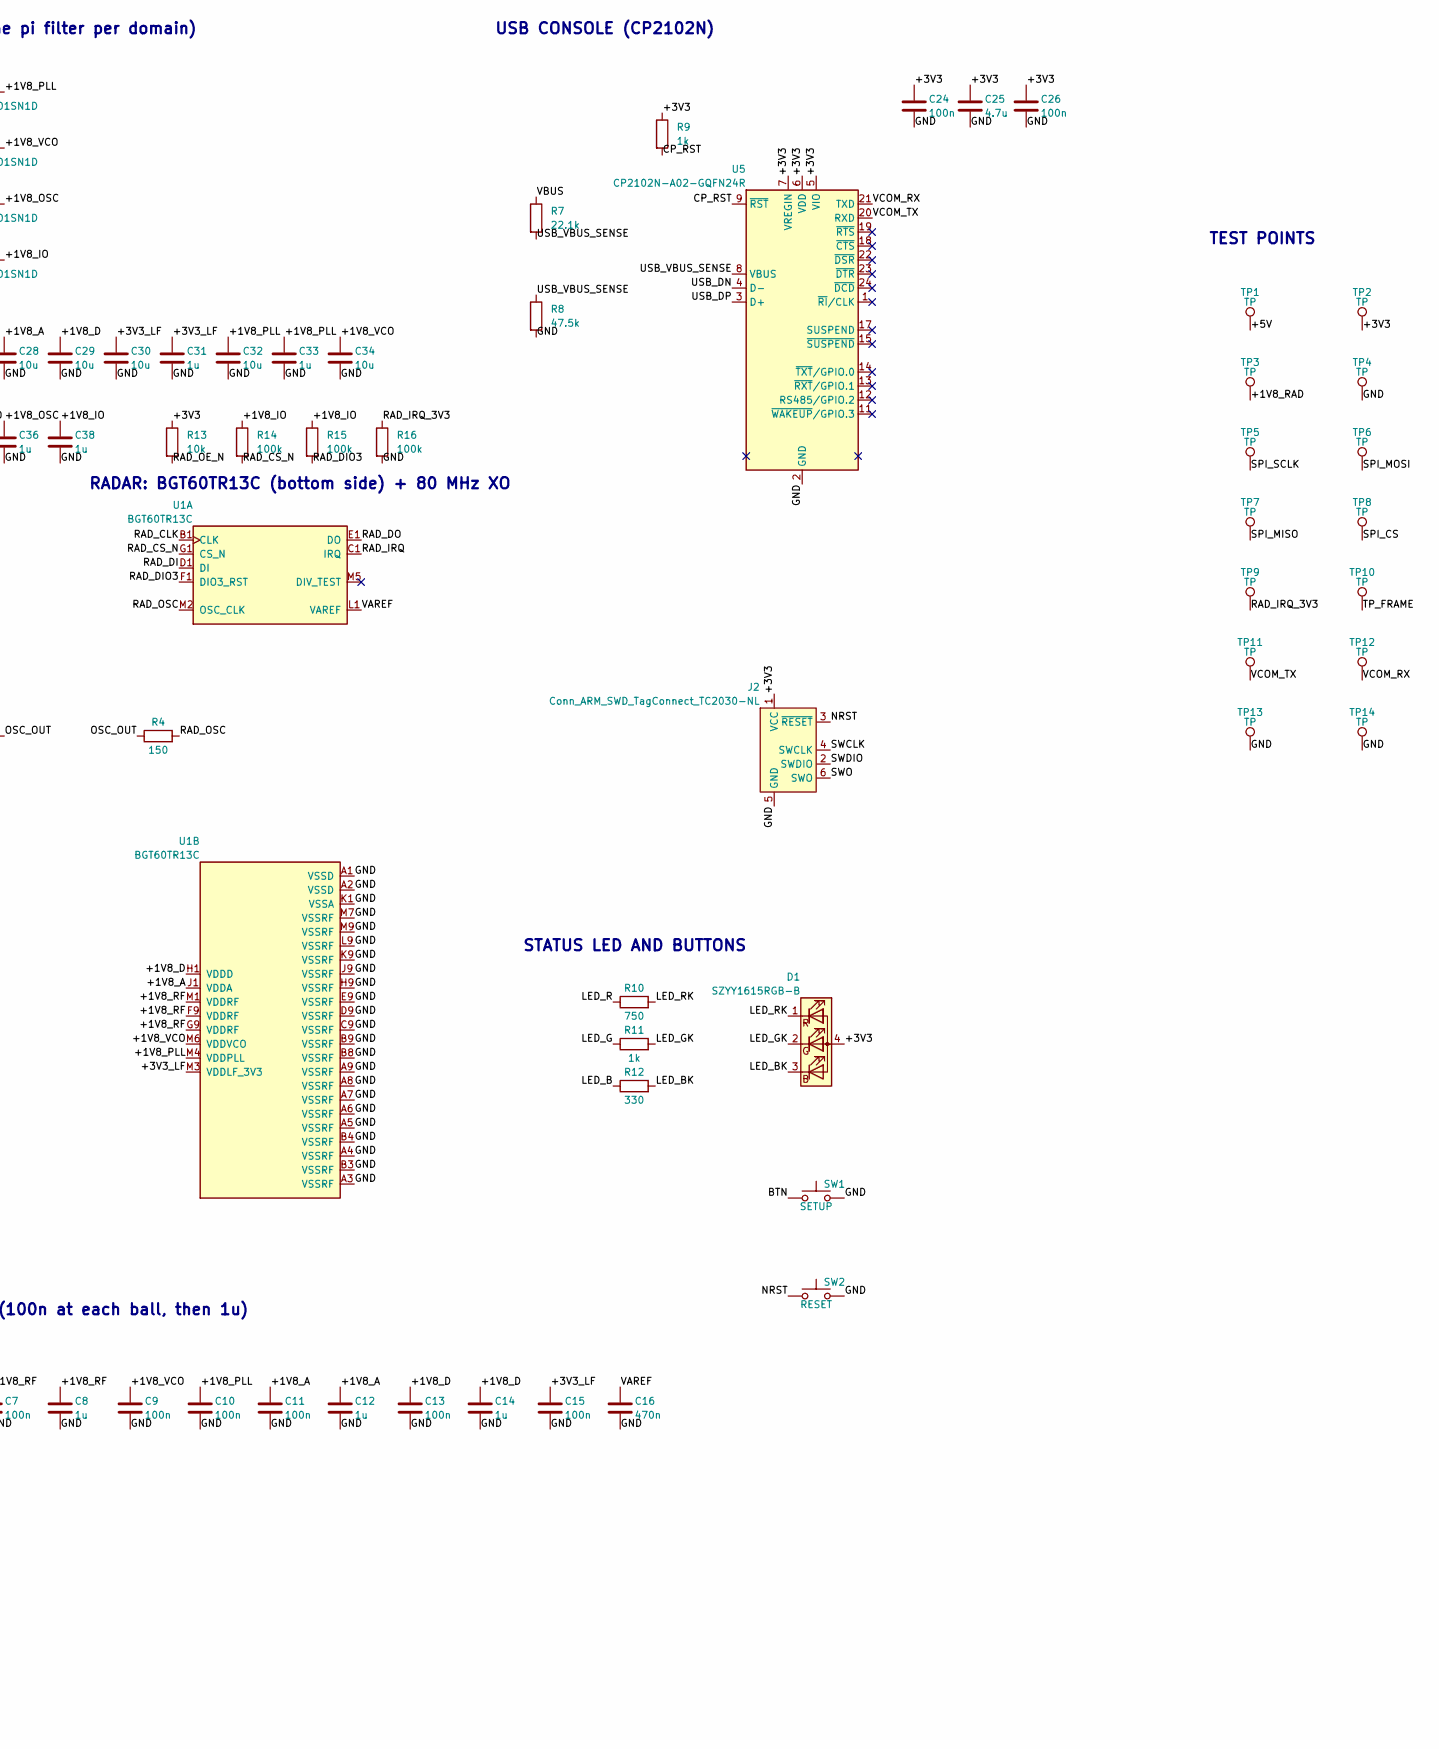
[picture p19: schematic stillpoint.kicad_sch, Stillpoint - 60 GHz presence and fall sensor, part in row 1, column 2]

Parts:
C1: 4.7u; C_0805_2012Metric; Voltage 25V; MPN CL21A475KAQNNNE; LCSC C1779
C2, C4, C22, C27, C28, C29, C30, C32, C34: 10u; C_0805_2012Metric; Voltage 25V; MPN CL21A106KAYNNNE; LCSC C15850
C3, C8, C12, C14, C31, C33, C35, C36, C38, C39: 1u; C_0402_1005Metric; Voltage 25V; MPN CL05A105KA5NQNC; LCSC C52923
C5, C6, C7, C9, C10, C11, C13, C15, C18, C19, C20, C21, C23, C24, C26: 100n; C_0402_1005Metric; Voltage 16V; MPN CL05B104KO5NNNC; LCSC C1525
C16: 470n; C_0402_1005Metric; Voltage 16V; MPN CC0402KRX5R7BB474; LCSC C527010
C17: 10n; C_0402_1005Metric; Voltage 50V; MPN CL05B103KB5NNNC; LCSC C15195
C25: 4.7u; C_0402_1005Metric; Voltage 10V; MPN CC0402MRX5R6BB475; LCSC C469468
D1: SZYY1615RGB-B; LED_RGB_1615_SZYY1615RGB-B; MPN SZYY1615RGB-B; LCSC C3029071
F1: 0.75A; Fuse_1206_3216Metric; Voltage 8V; MPN SMD1206P075TFT; LCSC C545214
FB1, FB2, FB3, FB4, FB5, FB6, FB7, FB8: BLM18KG601SN1D; L_0603_1608Metric; MPN BLM18KG601SN1D; LCSC C85833
J1: GT-USB-7051A; USB_C_Receptacle_G-Switch_GT-USB-7051A; MPN GT-USB-7051A; LCSC C2843970
J2: Conn_ARM_SWD_TagConnect_TC2030-NL; Tag-Connect_TC2030-IDC-NL_2x03_P1.27mm_Vertical; MPN TC2030-IDC-NL
R1, R2: 5.1k; R_0402_1005Metric; MPN 0402WGF5101TCE; LCSC C25905
R3, R14, R15, R16: 100k; R_0402_1005Metric; MPN 0402WGF1003TCE; LCSC C25741
R4: 150; R_0402_1005Metric; MPN 0402WGF1500TCE; LCSC C25082
R7: 22.1k; R_0402_1005Metric; MPN 0402WGF2212TCE; LCSC C43473
R8: 47.5k; R_0402_1005Metric; MPN 0402WGF4752TCE; LCSC C25896
R9, R11: 1k; R_0402_1005Metric; MPN 0402WGF1001TCE; LCSC C11702
R10: 750; R_0402_1005Metric; MPN 0402WGF7500TCE; LCSC C25132
R12: 330; R_0402_1005Metric; MPN 0402WGF3300TCE; LCSC C25104
R13: 10k; R_0402_1005Metric; MPN 0402WGF1002TCE; LCSC C25744
SW1: SETUP; SW_SPST_TL3342; MPN TL3342F160QG; LCSC C2886898
SW2: RESET; SW_SPST_TL3342; MPN TL3342F160QG; LCSC C2886898
TP1, TP2, TP3, TP4, TP5, TP6, TP7, TP8, TP9, TP10, TP11, TP12, TP13, TP14: TP; TestPoint_Pad_D1.0mm
U1: BGT60TR13C; MPN BGT60TR13CE6327XUMA1; LCSC C3606641
U2: MGM260PB32VNA5; SiliconLabs_MGM260P_12.9x15mm; MPN MGM260PB32VNA5
U3: TLV75733PDRVR; WSON-6-1EP_2x2mm_P0.65mm_EP1x1.6mm; MPN TLV75733PDRVR; LCSC C2868428
U4: TPS7A2018PDBVR; SOT-23-5; MPN TPS7A2018PDBVR; LCSC C963430
U5: CP2102N-A02-GQFN24R; QFN-24-1EP_4x4mm_P0.5mm_EP2.6x2.6mm; MPN CP2102N-A02-GQFN24R; LCSC C969151
U6: USBLC6-2SC6; SOT-23-6; MPN USBLC6-2SC6; LCSC C7519
U7, U8: SN74AVC4T245PWR; TSSOP-16_4.4x5mm_P0.65mm; MPN SN74AVC4T245PWR; LCSC C81461
Y1: KC2016K80.0000C1GE00; Crystal_SMD_2016-4Pin_2.0x1.6mm; MPN KC2016K80.0000C1GE00; LCSC C1988243

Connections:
/+1V8_A: C11.1, C12.1, C28.1, FB2.2, U1.J1 (VDDA)
/+1V8_D: C13.1, C14.1, C29.1, FB3.2, U1.H1 (VDDD)
/+1V8_IO: C19.1, C21.1, C38.1, FB8.2, R14.1, R15.1, U7.16 (VCCB), U8.16 (VCCB)
/+1V8_OSC: C17.1, C36.1, FB7.2, Y1.1 (OE), Y1.4 (Vdd)
/+1V8_PLL: C10.1, C32.1, C33.1, FB5.2, U1.M4 (VDDPLL)
/+1V8_RAD: C4.1, FB1.1, FB2.1, FB3.1, FB5.1, FB6.1, FB7.1, FB8.1, TP3.1, U4.5 (OUT)
/+1V8_RF: C5.1, C6.1, C7.1, C8.1, C27.1, FB1.2, U1.F9 (VDDRF), U1.G9 (VDDRF), U1.M1 (VDDRF)
/+1V8_VCO: C9.1, C34.1, C35.1, FB6.2, U1.M6 (VDDVCO)
/+3V3: C2.1, C3.1, C18.1, C20.1, C22.1, C23.1, C24.1, C25.1, C26.1, D1.4 (A), FB4.1, J2.1 (VCC), R9.1, R13.1, TP2.1, U2.15 (VDD), U3.1 (OUT), U4.1 (IN), U5.5 (VIO), U5.6 (VDD), U5.7 (VREGIN), U7.1 (VCCA), U7.2 (1DIR), U7.3 (2DIR), U8.1 (VCCA)
/+3V3_LF: C15.1, C30.1, C31.1, FB4.2, U1.M3 (VDDLF_3V3)
/+5V: C1.1, F1.2, TP1.1, U3.4 (EN), U3.6 (IN)
/BTN: SW1.1, U2.3 (PB03)
/CC1: J1.A5 (CC1), R1.1
/CC2: J1.B5 (CC2), R2.1
/CP_RST: R9.2, U5.9 (~RST)
/GND: C1.2, C2.2, C3.2, C4.2, C5.2, C6.2, C7.2, C8.2, C9.2, C10.2, C11.2, C12.2, C13.2, C14.2, C15.2, C16.2, C17.2, C18.2, C19.2, C20.2, C21.2, C22.2, C23.2, C24.2, C25.2, C26.2, C27.2, C28.2, C29.2, C30.2, C31.2, C32.2, C33.2, C34.2, C35.2, C36.2, C38.2, C39.2, J1.A1 (GND), J1.A12 (GND), J1.B1 (GND), J1.B12 (GND), J1.SH (SHIELD), J2.5 (GND), R1.2, R2.2, R3.2, R8.2, R16.2, SW1.2, SW2.2, TP4.1, TP13.1, TP14.1, U1.A1 (VSSD), U1.A2 (VSSD), U1.A3 (VSSRF), U1.A4 (VSSRF), U1.A5 (VSSRF), U1.A6 (VSSRF), U1.A7 (VSSRF), U1.A8 (VSSRF), U1.A9 (VSSRF), U1.B3 (VSSRF), U1.B4 (VSSRF), U1.B8 (VSSRF), U1.B9 (VSSRF), U1.C9 (VSSRF), U1.D9 (VSSRF), U1.E9 (VSSRF), U1.H9 (VSSRF), U1.J9 (VSSRF), U1.K1 (VSSA), U1.K9 (VSSRF), U1.L9 (VSSRF), U1.M7 (VSSRF), U1.M9 (VSSRF), U2.1 (GND), U2.14 (GND), U2.23 (GND), U2.32 (GND), U2.34 (GND), U2.35 (GND), U2.36 (GND), U3.3 (GND), U3.7 (GND), U4.2 (GND), U5.2 (GND), U5.25 (GND), U6.2 (GND), U7.8 (GND), U7.9 (GND), U8.2 (1DIR), U8.3 (2DIR), U8.8 (GND), U8.9 (GND), U8.10 (2B2), U8.11 (2B1), Y1.2 (GND)
/LED_B: R12.1, U2.4 (PB02)
/LED_BK: D1.3 (BK), R12.2
/LED_G: R11.1, U2.5 (PB01)
/LED_GK: D1.2 (GK), R11.2
/LED_R: R10.1, U2.6 (PB00)
/LED_RK: D1.1 (RK), R10.2
/NRST: J2.3 (~RESET), SW2.1, U2.31 (~RESET)
/OSC_OUT: R4.1, Y1.3 (OUT)
/RADAR_PWR_EN: R3.1, U2.26 (PC03), U4.3 (EN)
/RAD_CLK: U1.B1 (CLK), U7.10 (2B2)
/RAD_CS_N: R14.2, U1.G1 (CS_N), U7.13 (1B1)
/RAD_DI: U1.D1 (DI), U7.11 (2B1)
/RAD_DIO3: R15.2, U1.F1 (DIO3_RST), U7.12 (1B2)
/RAD_DO: U1.E1 (DO), U8.12 (1B2)
/RAD_IRQ: U1.C1 (IRQ), U8.13 (1B1)
/RAD_IRQ_3V3: R16.1, TP9.1, U2.24 (PC01), U8.4 (1A1)
/RAD_OE_N: R13.2, U2.25 (PC02), U7.14 (2~OE), U7.15 (1~OE), U8.14 (2~OE), U8.15 (1~OE)
/RAD_OSC: R4.2, U1.M2 (OSC_CLK)
/RAD_RST_3V3: U2.18 (PD03), U7.5 (1A2)
/SPI_CS: TP8.1, U2.19 (PD02), U7.4 (1A1)
/SPI_MISO: TP7.1, U2.22 (PC00), U8.5 (1A2)
/SPI_MOSI: TP6.1, U2.17 (PA08), U7.6 (2A1)
/SPI_SCLK: TP5.1, U2.16 (PA07), U7.7 (2A2)
/SWCLK: J2.4 (SWCLK), U2.8 (PA01/SWCLK)
/SWDIO: J2.2 (SWDIO), U2.9 (PA02/SWDIO)
/SWO: J2.6 (SWO), U2.10 (PA03/SWV)
/TP_FRAME: TP10.1, U2.2 (PB04)
/USB_DN: J1.A7 (D-), J1.B7 (D-), U5.4 (D-), U6.3 (I/O2), U6.4 (I/O2)
/USB_DP: J1.A6 (D+), J1.B6 (D+), U5.3 (D+), U6.1 (I/O1), U6.6 (I/O1)
/USB_VBUS_SENSE: R7.2, R8.1, U5.8 (VBUS)
/VAREF: C16.1, U1.L1 (VAREF)
/VBUS: C39.1, F1.1, J1.A4 (VBUS), J1.A9 (VBUS), J1.B4 (VBUS), J1.B9 (VBUS), R7.1, U6.5 (VBUS)
/VCOM_RX: TP12.1, U2.13 (PA06), U5.21 (TXD)
/VCOM_TX: TP11.1, U2.12 (PA05), U5.20 (RXD)

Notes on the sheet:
USB-C INPUT, ESD AND POWER
RADAR SUPPLY FILTERS (one pi filter per domain)
USB CONSOLE (CP2102N)
TEST POINTS
MCU: MGM260P (EFR32MG26, Matter / Thread)
LEVEL TRANSLATORS 3.3 V <-> 1.8 V
RADAR: BGT60TR13C (bottom side) + 80 MHz XO
STATUS LED AND BUTTONS
RADAR DECOUPLING (100n at each ball, then 1u)
POWER FLAGS (ERC)
DESIGN NOTES
Radar start-up (firmware): 1) RAD_OE_N=1 (R13 holds it in reset) 2) RADAR_PWR_EN=1 and wait >= 2 ms (TPS7A20 + XO settled)
3) SPI_CS=1 and RAD_RST_3V3=1, then RAD_OE_N=0 4) reset through DIO3 with CS_N=1 (R14/R15 hold CS_N and DIO3 high while OE is inactive)
Pi filter per domain (UG091722 sec. 3.3): +1V8_RAD -> FB1..FB3, FB5..FB8 (RF, A, D, PLL, VCO, OSC, IO); +3V3 -> FB4 (LF). Ferrites BLM18KG601SN1D (0.15 ohm, 1.3 A)

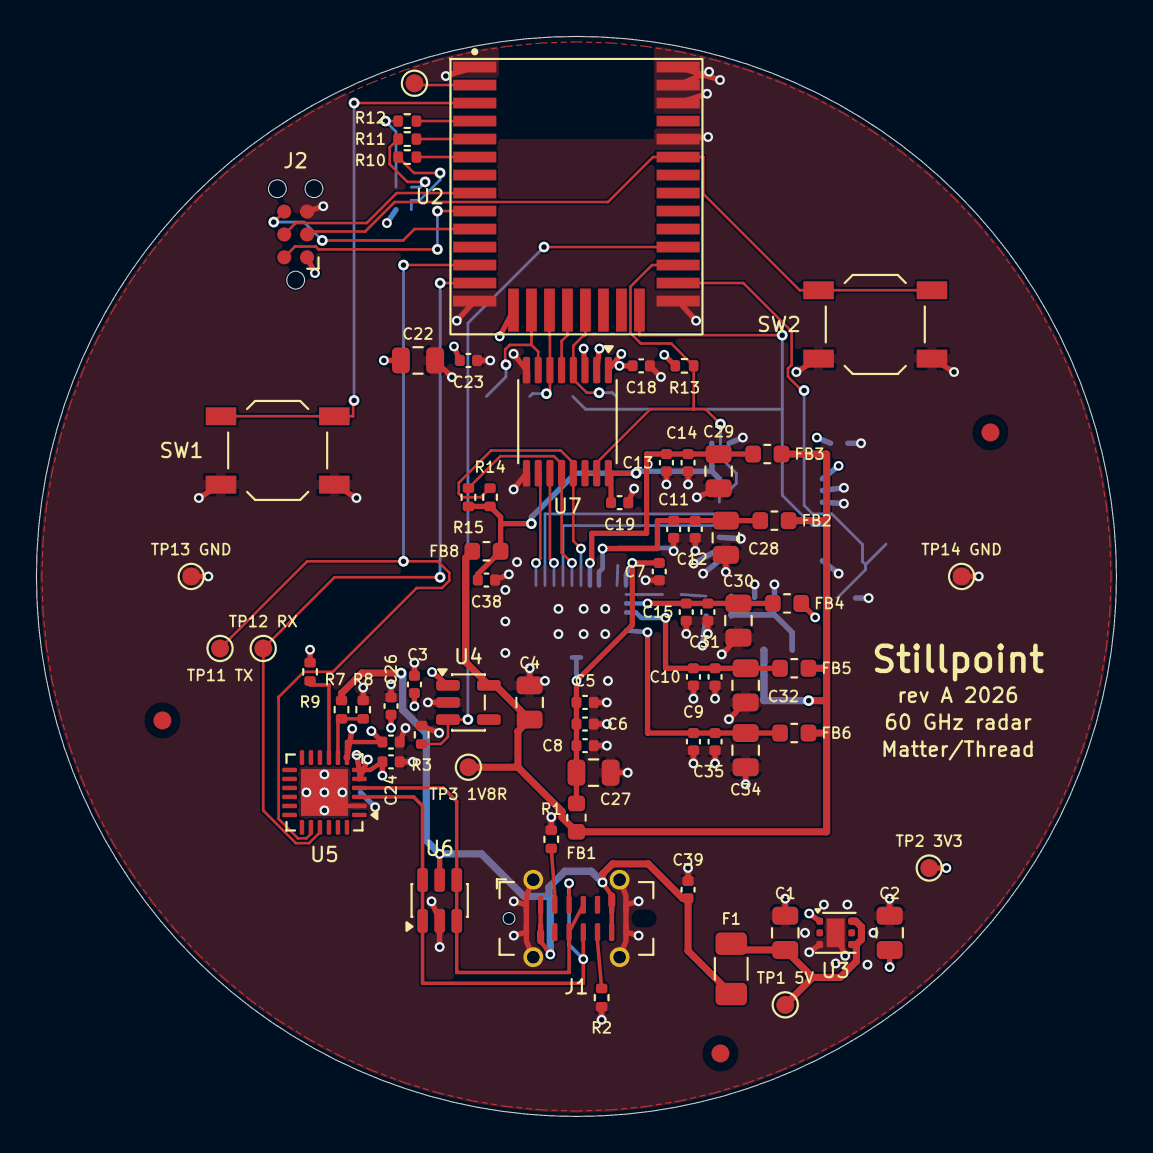
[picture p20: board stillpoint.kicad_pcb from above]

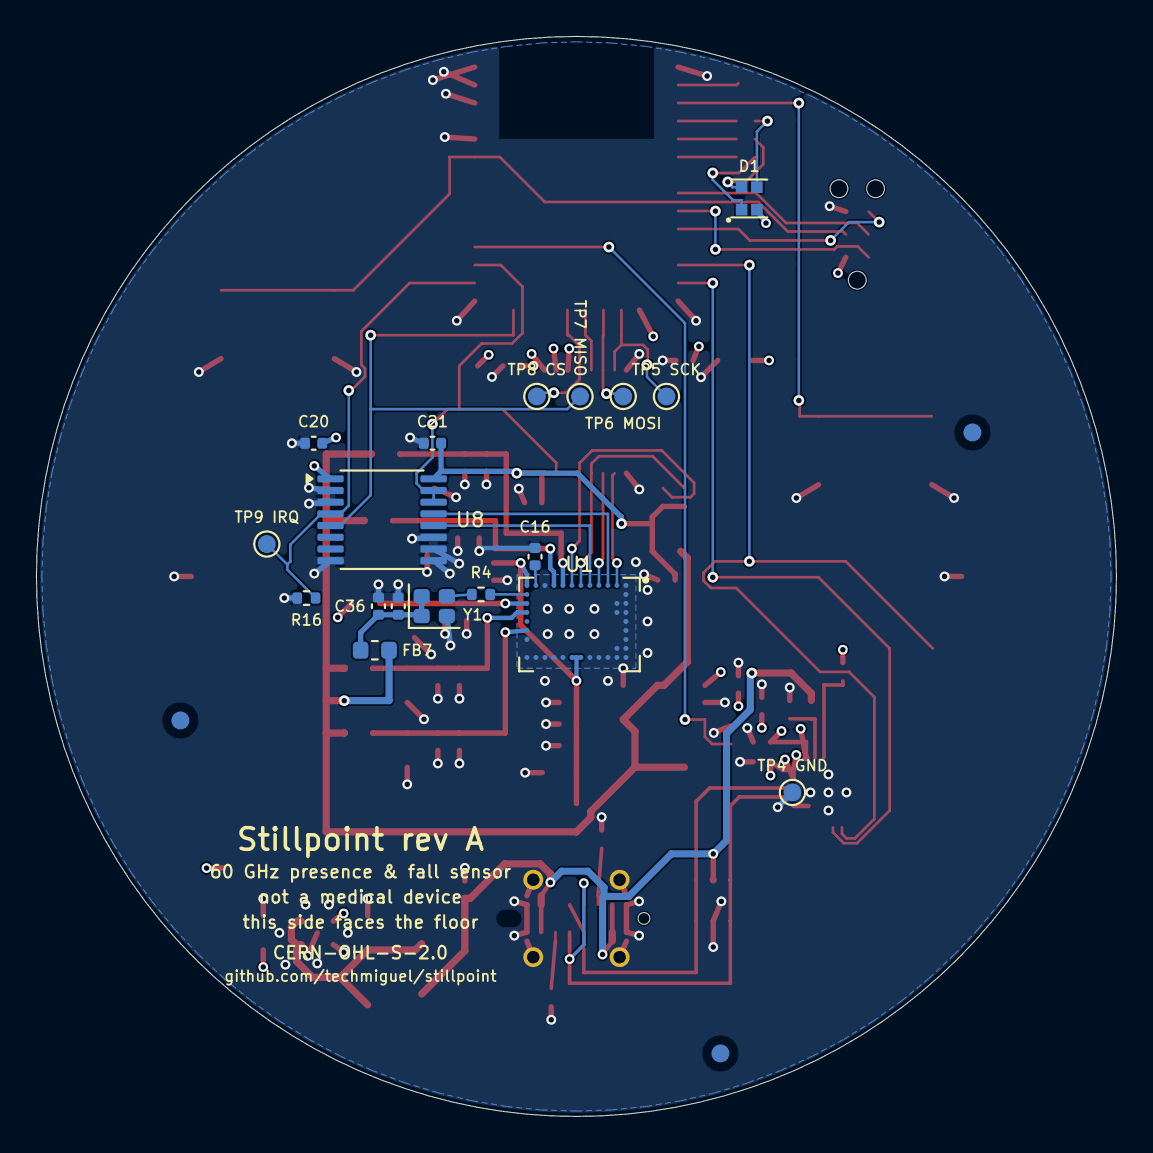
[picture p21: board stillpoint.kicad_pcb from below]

Board: 4 copper layers, 60.0 x 60.0 mm, 95 parts (21 on the bottom side), 50 nets.

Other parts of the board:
FID1, FID2, FID3, FID4, FID5, FID6: Fiducial; Fiducial_1mm_Mask2mm

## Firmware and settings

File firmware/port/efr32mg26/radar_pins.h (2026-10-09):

/* Pins of the rev A board (hardware/stillpoint.kicad_sch, U2 = MGM260P).
 * On the development kit, adjust them to the wiring of the radar board. */
#pragma once
#include "em_gpio.h"

/* Radar: the signals leave from the module's bottom pad row (pads 16-22), which
 * faces the U7/U8 translators and the radar, so no route crosses another.
 * PD00/PD01 (pads 21/20) stay free for an optional 32.768 kHz crystal. */
#define RADAR_CS_PORT gpioPortD          /* pad 19, SPI_CS -> U7 1A1 -> CS_N */
#define RADAR_CS_PIN 2
#define RADAR_RST_PORT gpioPortD         /* pad 18, RAD_RST_3V3 -> U7 1A2 -> DIO3 */
#define RADAR_RST_PIN 3
#define RADAR_IRQ_PORT gpioPortC         /* pad 24, RAD_IRQ_3V3 <- U8 1A1 <- IRQ */
#define RADAR_IRQ_PIN 1
/* Enables U4 (TPS7A2018, +1V8_RAD); R3 keeps it off during reset. */
#define RADAR_PWR_EN_PORT gpioPortC      /* pad 26 */
#define RADAR_PWR_EN_PIN 3
/* 1OE/2OE of U7 and U8, active low; R13 holds it high (outputs high-Z)
 * until the firmware pulls it low. */
#define RADAR_OE_N_PORT gpioPortC        /* pad 25 */
#define RADAR_OE_N_PIN 2

/* SPI (spidrv instance "radar", EUSART1; EUSART routing accepts any port
 * on the MGM260P, datasheet table 6.x):
 *   SCLK PA07 (pad 16) · MOSI/TX PA08 (pad 17) · MISO/RX PC00 (pad 22).
 * CS driven as GPIO (RADAR_CS_*), not by the peripheral. */
#define RADAR_SPI_SCLK_PORT gpioPortA
#define RADAR_SPI_SCLK_PIN 7
#define RADAR_SPI_MOSI_PORT gpioPortA
#define RADAR_SPI_MOSI_PIN 8
#define RADAR_SPI_MISO_PORT gpioPortC
#define RADAR_SPI_MISO_PIN 0

/* Rest of the board */
#define BOARD_BTN_PORT gpioPortB         /* pad 3, SW1 to GND: internal pull-up */
#define BOARD_BTN_PIN 3
#define BOARD_TP_FRAME_PORT gpioPortB    /* pad 2, TP10 "frame processed" */
#define BOARD_TP_FRAME_PIN 4
/* RGB LED D1 (common anode to +3V3): low = on */
#define BOARD_LED_R_PORT gpioPortB       /* pad 6, R10 750 Ω */
#define BOARD_LED_R_PIN 0
#define BOARD_LED_G_PORT gpioPortB       /* pad 5, R11 1 kΩ */
#define BOARD_LED_G_PIN 1
#define BOARD_LED_B_PORT gpioPortB       /* pad 4, R12 330 Ω */
#define BOARD_LED_B_PIN 2
/* Console (CP2102N U5). Net names are from the CP2102N side:
 * VCOM_TX = CP2102N TXD -> MCU RX; VCOM_RX = CP2102N RXD <- MCU TX. */
#define BOARD_VCOM_RX_PORT gpioPortA     /* pad 12, net VCOM_TX */
#define BOARD_VCOM_RX_PIN 5
#define BOARD_VCOM_TX_PORT gpioPortA     /* pad 13, net VCOM_RX */
#define BOARD_VCOM_TX_PIN 6

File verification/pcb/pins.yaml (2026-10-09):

# Critical pins copied from the DATASHEET (not from the schematic). Prefix ~ means regex.
# Rails that the rev A rework splits (RF/PLL/VCO, OSC, IO) use regexes so the
# check survives the rename; the ball/pin number is what must not move.

# Infineon BGT60TR13C, datasheet v2.4.6 Table 1 (PG-VF2BGA-40-1)
U1:
  B1: "~.*RAD_CLK"
  C1: "~.*RAD_IRQ"
  D1: "~.*RAD_DI"
  E1: "~.*RAD_DO"
  F1: "~.*RAD_DIO3"
  G1: "~.*RAD_CS_N"
  H1: "~.*1V8_D"
  J1: "~.*1V8_A"
  K1: GND
  L1: "~.*VAREF"
  M2: "~.*RAD_OSC"
  M3: "~.*3V3_LF"
  M4: "~.*1V8_(PLL|RF)"
  M6: "~.*1V8_(VCO|RF)"
  M1: "~.*1V8_RF"
  F9: "~.*1V8_RF"
  G9: "~.*1V8_RF"
  A1: GND
  A9: GND
  M9: GND

# Silicon Labs MGM260P, datasheet rev 1.1 Table 6.1 (pins 1-36)
U2:
  1: GND
  14: GND
  15: "+3V3"
  23: GND
  8: "~.*SWCLK"
  9: "~.*SWDIO"
  # Radar interface on the bottom pad row (EUSART1 routable to any port, Table 6.x);
  # PD00/PD01 (pads 21/20) left free for an optional 32.768 kHz crystal.
  16: "~.*SPI_SCLK"        # PA07
  17: "~.*SPI_MOSI"        # PA08
  18: "~.*RAD_RST_3V3"     # PD03
  19: "~.*SPI_CS"          # PD02
  22: "~.*SPI_MISO"        # PC00
  24: "~.*RAD_IRQ_3V3"     # PC01
  25: "~.*RAD_OE_N"        # PC02
  26: "~.*RADAR_PWR_EN"    # PC03
  12: "~.*VCOM_TX"         # PA05 (MCU RX)
  13: "~.*VCOM_RX"         # PA06 (MCU TX)
  3: "~.*BTN"              # PB03
  31: "~.*NRST"
  32: GND

# Silicon Labs CP2102N QFN24, datasheet section 5.2
U5:
  2: GND
  3: "~.*USB_DP"
  4: "~.*USB_DN"
  5: "+3V3"
  6: "+3V3"
  7: "+3V3"
  8: "~.*USB_VBUS_SENSE"
  9: "~.*CP_RST"
  20: "~.*VCOM_TX"
  21: "~.*VCOM_RX"

# ST USBLC6-2SC6, datasheet functional diagram (1/6 I/O1, 2 GND, 3/4 I/O2, 5 VBUS)
U6:
  2: GND
  5: "~.*VBUS"

# G-Switch GT-USB-7051A (USB-C 16P)
J1:
  A1: GND
  B12: GND
  A4: "~.*VBUS"
  B9: "~.*VBUS"
  A5: "~.*CC1"
  B5: "~.*CC2"
  A6: "~.*USB_DP"
  A7: "~.*USB_DN"

# Yongyu SZYY1615RGB-B (LCSC C3029071 symbol/footprint): 1 R, 2 G, 3 B cathodes, 4 common anode
D1:
  1: "~.*LED_RK"
  2: "~.*LED_GK"
  3: "~.*LED_BK"
  4: "+3V3"

# TI TLV75733P WSON-6 (DRV): 1 OUT, 3 GND, 4 EN, 6 IN, 7 thermal pad
U3:
  1: "+3V3"
  3: GND
  4: "+5V"
  6: "+5V"
  7: GND

# TI TPS7A2018 SOT-23-5 (DBV): 1 IN, 2 GND, 3 EN, 5 OUT
U4:
  1: "+3V3"
  2: GND
  3: "~.*RADAR_PWR_EN"
  5: "~.*1V8_RAD"

# Kyocera KC2016 XO: 1 ST, 2 GND, 3 OUT, 4 VCC
Y1:
  1: "~.*1V8_OSC"
  2: GND
  3: "~.*OSC_OUT"
  4: "~.*1V8_OSC"

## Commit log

2026-10-09 radar60 rev A: privacy-first 60 GHz radar presence and fall sensor
    Open hardware ceiling sensor: Infineon BGT60TR13C 60 GHz radar and a
    Silicon Labs MGM260P (EFR32MG26) running everything on the device and
    reporting over Matter on Thread.
    - hardware/: KiCad 10 schematic and routed 4-layer Ø60 mm board,
    JLCPCB fabrication files; ERC/DRC/parity clean, kicadverify PASS.
    - tools/pcb_build/: placement and critical routing as scripts.
    - mechanical/: FreeCAD enclosure, lid and λ/2 radome checked against
    the board STEP.
    - firmware/: portable C (DSP, tracking, int8 inference, fail-safe
    decision) tested bit-for-bit against the Python reference; EFR32MG26
    port with Matter bridge and UART dia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
    [BOM_JLCPCB.csv, enclosure.step, enclosure.stl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]
2026-10-09 Rename to Stillpoint; product renders; leaner README
    - Project, KiCad files, libraries, silkscreen, schematic title, Matter
    cluster and docs renamed from radar60 to Stillpoint.
    - tools/render_views.py: ray-traced renders of the board and of the
    exploded enclosure (FreeCAD shell + lid added as 3D models), studio
    backdrop, share-page cutouts and the Open Graph image.
    - README: exploded hero image, enclosure section; checks row, status,
    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
    [enclosure.step, enclosure.stl, lid.step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]
